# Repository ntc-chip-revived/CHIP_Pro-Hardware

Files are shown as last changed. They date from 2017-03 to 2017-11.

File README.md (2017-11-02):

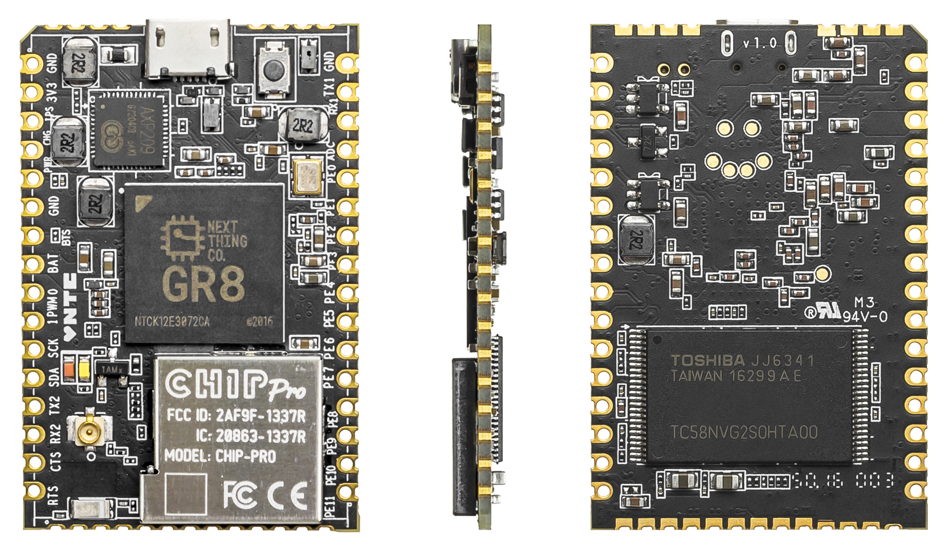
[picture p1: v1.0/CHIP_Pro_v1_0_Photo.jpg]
Image of C.H.I.P. Pro v1.0


# C.H.I.P. Pro Hardware Versions

v1.0 = C.H.I.P. Pro<br>
v0.9 = Early Pre-Cert Developer Kits

# Source Files
C.H.I.P. Pro is designed using OrCAD! 
<br>A free "lite" viewer is available at www.orcad.com

# Documentation
#### C.H.I.P. Pro Datasheet:
https://github.com/NextThingCo/CHIP_Pro-Hardware/blob/master/Datasheets/CHIP_PRO_Datasheet_v1.0.pdf

#### C.H.I.P. Pro Docs:
https://docs.getchip.com/chip_pro.html

#### C.H.I.P. Pro Dev Kit Docs:
https://docs.getchip.com/chip_pro_devkit.html

# Compliance
C.H.I.P. Pro is tested for compliance with, and registered as indicated below with the following regulatory bodies:
REACH,
ROHS,
CE,
FCC (ID: 2AF9F-1337R, 47 CFR 15 Modular Transmitter when used with pre-certified antennas as listed in Datasheet),
IC (ID: 20863-1337R, HVIN CHIP-PRO)

# License
<br />This work is licensed under a <a rel="license" href="http://creativecommons.org/licenses/by/4.0/">Creative Commons Attribution 4.0 International License</a>.

# Contact NTC
**Purchasing:** sales@nextthing.co 
**Technical:** pro@nextthing.co <br>
Join the conversation at https://bbs.nextthing.co/c/CHIP-Pro

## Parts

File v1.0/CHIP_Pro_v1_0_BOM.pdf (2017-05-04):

*********************************************************************************************************************************************

# Next Thing Co. Creative Commons: CC-BY-SA

## docs.nextthing.co

*********************************************************************************************************************************************

### PCBA BOM

Model | C.H.I.P. Pro
Version | v1.0
Item Number | 100456
Date | 5/4/17
Document Revision | v1.01
NAME | CATEGORY | QTY | REF DES | MFG P/N | MANUFACTURER
IC CPU GR8 BGA252 | IC | 1 | U1 | | Next Thing Co.
AXP209 | IC | 1 | U2 | | Allwinner
IC DC-DC LP3220SAB5F SOT23-5 | IC | 2 | U3, U4 | MT3410LA | Pace Electronics
SMD MODULE WIFI | IC | 1 | U5 | 8723DS | FN-link
SMD INDUCTOR 2.2uH DCR<0.1R-1.7A 3518 | Inductor | 5 | L1,L2,L3,L4,L5 | MPA3015S2R2M | Mottotech
SMD LED 0603 white color (e.g. Everlight QTLP603CIWTR or similar) | LED | 1 | D1 | HQ19-2101UWC | HQG
SMD LED EC01-0603QRC-E-Ag pink color (e.g. lowcost versions of Panasonic LNJP12X8ARA or similar) | LED | 1 | D2 | HQ19-2132UFD | HQG
WiFi/Bluetooth Antenna | Antenna | 1 | ANT2 | AA055 | Unictron
SMD TRANSISTOR MMBT3904 NPN SOT-23 | Transistor | 1 | Q2 | MMBT3904 | Pace Electronics
SMD C-MOS N-channel BSN20 SOT-23 | Transistor | 1 | Q1 | 2N7002K | Pace Electronics
SMD JACK MICRO USB A01SB141BH2_4A | Jack | 1 | J4 | U-F-M5DW-Y | Han Rong Parts Co.
SMD KEY SW_4P_TC3061B/IT-1100AE | Switch | 1 | SW2 | K2-1807SA | Han Rong Parts Co.
CHIP CAP 0201 47P 16V NPO | Capacitor | 2 | C16,C31 | CC0201JRNPO8BN470 | YAGEO
CHIP CAP 0201 102 16V +/-20% | Capacitor | 3 | C11,C15,C84 | CC0201KRX7R8BB102 | YAGEO
CHIP CAP 0201 104 10V +/-20% | Capacitor | 1 | C54 | CC0201KRX5R6BB104 | YAGEO
CHIP CAP 0402 105 10V +/-20% | Capacitor | 26 | C4,C18,C19,C23,C34, C52,C57,C58,C60,C61, C62,C63,C65,C69,C70, C71,C72,C74,C77,C78, C79,C80,C81,C82,C83, C85 | CC0402KRX5R6BB105 | YAGEO
CHIP CAP 0603 4.7uF 10V +/-20% | Capacitor | 8 | C5, C6,C7,C21,C26,C27,C 33,C55 | CC0603KRX5R6BB475 | YAGEO
CHIP CAP 0603 10uF 10V +/-20% | Capacitor | 7 | C8,C9,C12,C13,C17,C 28,C48 | CC0603MRX5R6BB106 | YAGEO
CHIP CAP 0805 22uF 10V +/-20% | Capacitor | 2 | C44,C45 | CC0805MKX5R5BB226 | YAGEO
CHIP RESISTOR 0201 24Ohm 1/20W +/-5% | Resistor | 2 | R100,R101 | RC0201JR-0724RL | YAGEO
CHIP RESISTOR 0201 240Ohm 1/16W +/-1% | Resistor | 2 | R2,R3 | RC0201FR-07240RL | YAGEO
CHIP RESISTOR 0201 1KOhm 1/20W +/-5% | Resistor | 3 | R15,R20,R21 | RC0201JR-071KL | YAGEO
CHIP RESISTOR 0201 2KOhm 1/16W +/-1% | Resistor | 2 | R1,R4 | RC0201FR-072KL | YAGEO
CHIP RESISTOR 0201 2.2KOhm 1/20W +/-5% | Resistor | 5 | R22,R59,R60,R61,R62 | RC0201JR-072K2L | YAGEO
CHIP RESISTOR 0201 10KOhm 1/20W +/-5% | Resistor | 8 | NSR1,R5,R9,R10,R46, R47,R51,R64 | RC0201JR-0710KL | YAGEO
CHIP RESISTOR 0201 33KOhm 1/20W +/-5% | Resistor | 5 | R38,R39,R41,R42,R43 | RC0201JR-0733KL | YAGEO
CHIP RESISTOR 0201 47KOhm 1/20W +/-5% | Resistor | 2 | R14,R18 | RC0201JR-0747KL | YAGEO
CHIP RESISTOR 0201 100KOhm 1/20W +/-5% | Resistor | 2 | R48,R49 | RC0201JR-07100KL | YAGEO
CHIP RESISTOR 0201 0Ohm 1/20W +/-5% | Resistor | 2 | R36,R58 | RC0201JR-070RL | YAGEO
CHIP RESISTOR 0402 1Ohm 1/16W +/-5% | Resistor | 2 | R8,R53 | RC0402JR-071RL | YAGEO
CHIP RESISTOR 0201 100KOhm 1/20W +/-1% | Resistor | 2 | R11,R16 | RC0201FR-07100KL | YAGEO
CHIP RESISTOR 0201 150KOhm 1/20W +/-1% | Resistor | 1 | R17 | RC0201FR-07150KL | YAGEO
CHIP RESISTOR 0201 200KOhm 1/20W +/-1% | Resistor | 2 | R13,R57 | RC0201FR-07200KL | YAGEO
CHIP RESISTOR 0603 0.03Ohm 1/8W +/-1% | Resistor | 1 | R7 | RL0603FR-070R03L | YAGEO
CHIP CAP 0201 8p 16V NPO | Capacitor | 1 | C49 | 1.0pF C0201 | YAGEO
CHIP RESISTOR 0201 2KΩ 1/16W ±5% | Resistor | 1 | R19 | RC0201JR-072KL | YAGEO
SLC NAND TC58NVG2S0HTA00 | Memory | 1 | U7 | TC58NVG2S0HTA00 | Toshiba
CHIP CAP 0201 104 6.3V +/-20% | Capacitor | 23 | C1,C2,C3,C22,C32,C3 5,C37,C64,C66,C75,C8 6,C88,C90,C91,C93,C9 4,C95,C96,C97,C98,C1 48,C151,C153 | CC0201KRX5R5BB104 | YAGEO
CHIP RESISTOR 0201 442KΩ 1/16W ±1% | Resistor | 1 | R12 | RC0201FR-07442KL | YAGEO
WiFi Module RF Shield | Sheet metal | 1 | | n/a | Custom
RDASW282/XMSS1R6G0PA-001 | Switch | 1 | U8 | RDASW282 | Arrow China
CHIP RESISTOR 0402 0Ω 1/8W | Resistor | 1 | R32 | RC0402JR-070RL | YAGEO
CHIP CAP 0603 4.7uF 6.3V +/-20% | Capacitor | 9 | C20,C24,C25,C29,C30, C36,C53,C56,C89 | CC0603KRX5R5BB475 | YAGEO
CHIP CAP 0603 10uF 6.3V +/-20% | Capacitor | 7 | C10,C14,C59,C68,C76, C87,C92 | CC0603MRX5R5BB106 | YAGEO
CHIP CAP 0201 20P 16V NPO | Capacitor | 2 | C67, C73 | CC0201JRNPO8BN200 | YAGEO
SMD CRYSTAL 24MHz ±10ppm 20pF | Crystal | 1 | X1 | 7U024000W120 | SJK Crystal Tech
I-PEX Connector | Connector | 1 | ANT1 | C-7.005A0 | HuaChuangxiang
0402 ESD Diode SE10F10B5.0MA | Diode | 5 | ESD1, ESD2, ESD5, ESD3, ESD4 | SE10F10B5.0MA | 芯晶图
SDCW2012-2-900TF | Inductor | 2 | L9,L10 | SDCW2012-2-900TF | Sunlord
| Capacitor | 1 | R33 | 1.2pF C0201 | YAGEO
PCB + PCBA | | 1 | PCB Material + PCBA

1

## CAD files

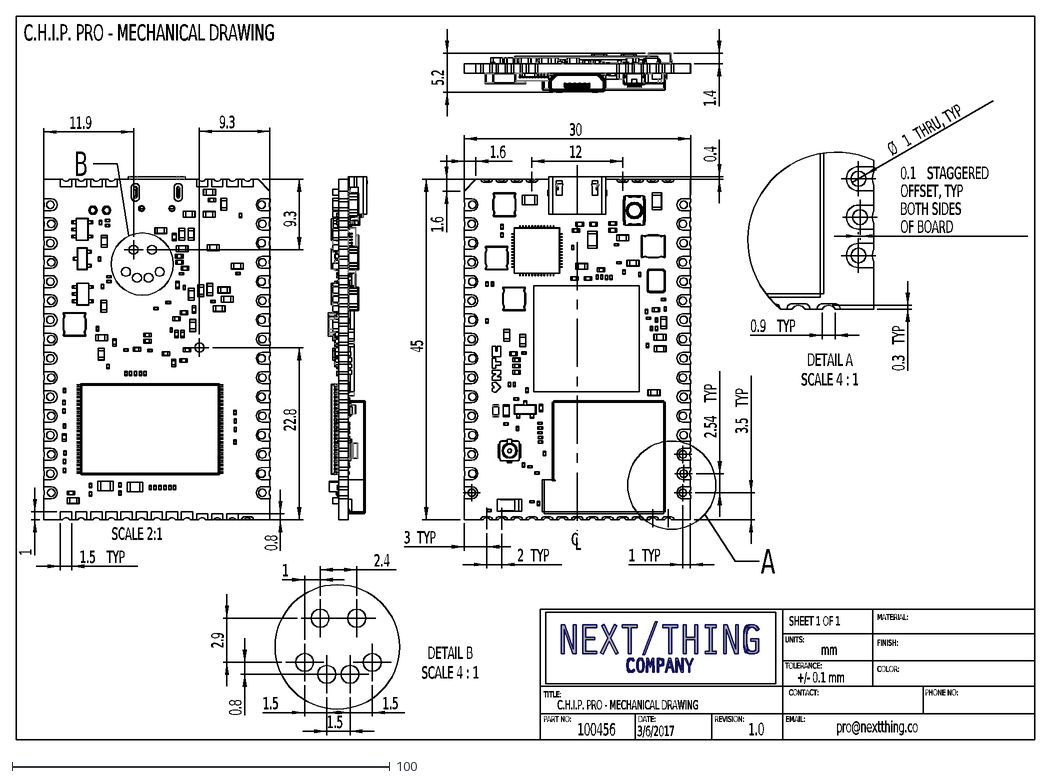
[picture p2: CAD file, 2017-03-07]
Mechanical_Documents/NTC-100456_C.H.I.P._Pro_Mechanical_Drawing_v1.0_2017-03-06.DXF
C.H.I.P. PRO - MECHANICAL DRAWING
1.0
+/- 0.1 mm
FINISH:
COLOR:
REVISION:
UNITS:
TITLE:
mm
pro@nextthing.co
EMAIL:
CONTACT:
SHEET 1 OF 1
DATE:
PHONE NO:
MATERIAL:
3/6/2017
PART NO:
TOLERANCE:
100456
45
30
0.4
1.6
12
2.54
TYP
3.5
1
3
2
C
L
A
1.4
5.2
11.9
9.3
22.8
0.8
1.5
SCALE 2:1
B
0.3
0.1
STAGGERED
OFFSET, TYP
BOTH SIDES
OF BOARD
0.9
Ø
THRU, TYP
DETAIL A
SCALE 4 : 1
2.9
2.4
DETAIL B

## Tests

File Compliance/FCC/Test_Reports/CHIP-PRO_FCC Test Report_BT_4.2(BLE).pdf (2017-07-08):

Report No.: AGC06426160901FE08 Page 1 of 26

# FCC Test Report

## Report No.: AGC08116161202FE08

FCC ID | : 2AF9F-1337R
APPLICATION PURPOSE | : Original Equipment

### PRODUCT DESIGNATION : CHIP Pro

BRAND NAME | : CHIP Pro
MODEL NAME | : CHIP-PRO
CLIENT | : Next Thing Co
DATE OF ISSUE | : Mar. 22, 2017
STANDARD(S) TEST PROCEDURE(S) | : FCC Part 15.247 KDB 558074 v03r05
REPORT VERSION | : V1.0

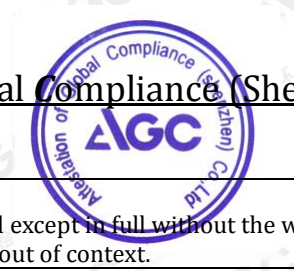
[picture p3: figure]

# Attestation of Global Compliance (Shenzhen) Co., Ltd

### CAUTION:

This report shall not be reproduced except in full without the written permission of the test laboratory and shall not be quoted out of context.

Report No.: AGC08116161202FE08 Page 2 of 26

Report Revise Record

Report Version | Revise Time | Issued Date | Valid Version | Notes
V1.0 | / | Mar. 22, 2017 | Valid | Original Report

Page 3 of 26

TABLE OF CONTENTS

Page 4 of 26

Page 5 of 26

### 1. VERIFICATION OF COMPLIANCE

Applicant | Next Thing Co
Address | 1940 Union St#32, Oakland CA
Manufacturer | Next Thing Co
Address | 1940 Union St#32, Oakland CA
Product Designation | CHIP Pro
Brand Name | CHIP Pro
Test Model | CHIP-PRO
Date of test | Feb. 20, 2017~Mar. 16, 2017
Deviation | None
Condition of Test Sample | Normal
Report Template | AGCRT-US-BLE/RF

WE HEREBY CERTIFY THAT:

The above equipment was tested by Dongguan Precise Testing Service Co., Ltd. The test data, data evaluation, test procedures, and equipment configurations shown in this report were made in accordance with the procedures given in ANSI C63.10 (2013) and the energy emitted by the sample EUT tested as described in this report is in compliance with requirement of FCC Part 15 Rules requirement.

Tested By

Donjon Huang(Huang
Dongyang)

Mar. 16, 2017

Reviewed By

Bart Xie(Xie Xiaobin) | Mar. 22, 2017

Approved By

Solger Zhang(Zhang Hongyi)
Authorized Officer | Mar. 22, 2017

Page 6 of 26

2.GENERAL INFORMATION
2.1PRODUCT DESCRIPTION
The EUT is designed as “CHIP Pro ”. It is designed by way of utilizing the FHSS technology to achieve the system operation.

A major technical description of EUT is described as following

### 2.2 RELATED SUBMITTAL(S)/GRANT(S)

This submittal(s) (test report) is intended for FCC ID: 2AF9F-1337R filing to comply with Section 15.247of the FCC Part 15, Subpart C Rules.

2.3TEST METHODOLOGY
All measurements contained in this report were conducted with KDB 558074 D01 DTS Meas Guidance v03r05, American National Standard for Methods of Measurement of Radio-Noise Emissions from Low-Voltage Electrical and Electronic Equipment in the range of 9 kHz to 40 GHz.
The equipment under test (EUT) was configured to measure its highest possible emission level. The test modes were adapted accordingly in reference to the Operating Instructions. The EUT was tested in all three orthogonal planes and the worse case was showed.

### 2.4 TEST FACILITY

### 2.5 SPECIAL ACCESSORIES

Refer to section 2.2.

Operation Frequency | 2.402 GHz to 2.480GHz
Bluetooth Version | V4.2
Modulation | GFSK
Number of channels | 40 Channel(37 Hopping Channel,3 advertising Channel)
Antenna Designation | AA107:PCB Antenna HCX-P321:PCB Antenna FXP73: PCB Antenna AA055: Ceramic Antenna
Antenna Gain | AA107:3.3dBi; HCX-P321:2dBi; FXP73:2.5dBi; AA055:2.5dBi
Hardware Version | V1.0
Software Version | Fcc-20170109-b6281346
Power Supply | DC5V by PC
Site | Dongguan Precise Testing Service Co., Ltd.
Location | Building D,Baoding Technology Park,Guangming Road2,Dongcheng District, Dongguan, Guangdong, China,
FCC Registration No. | 371540
Description | The test site is constructed and calibrated to meet the FCC requirements in documents ANSI C63.10:2013.

Page 7 of 26

### 2.6 EQUIPMENT MODIFICATIONS

Not available for this EUT intended for grant.

### 3. SYSTEM TEST CONFIGURATION

### 3.1 CONFIGURATION OF TESTED SYSTEM

Configuration:

USB Cable

### 3.2 EQUIPMENT USED IN TESTED SYSTEM

Item | Equipment | Model No. | ID or Specification | Note
1 | CHIP Pro | CHIP-PRO | 2AF9F-1337R | EUT
2 | Lenovo | B460 | WB03928113 | PC
3 | USB Cable | N/A | N/A | Accessory

ALL TEST EQUIPMENT LIST
FOR RADIATED EMISSION TEST (BELOW 1GHZ)
Radiated Emission Test Site
Name of Equipment | Manufacturer | Model Number | Serial
| | | Number | Last Calibration | Due Calibration
EMI Test Receiver | Rohde & Schwarz | ESCI | 101417 | July 3, 2016 | July 2, 2017
Trilog Broadband Antenna (25M-1GHz) | SCHWARZBECK | VULB9160 | 9160-3355 | July 3, 2016 | July 2, 2017
Signal Amplifier | SCHWARZBECK | BBV 9475 | 9745-0013 | July 3, 2016 | July 2, 2017
RF Cable | SCHWARZBECK | AK9515E | 96221 | July 3, 2016 | July 2, 2017
3m Anechoic Chamber | CHENGYU | 966 | PTS-001 | June 5, 2016 | June 4, 2017
MULTI-DEVICE Positioning Controller | Max-Full | MF-7802 | MF780208339 | N/A | N/A
Active loop antenna (9K-30MHz) | Schwarzbeck | FMZB1519 | 1519-038 | June 5, 2016 | June 4, 2017
Spectrum analyzer | Agilent | E4407B | MY46185649 | June 5, 2016 | June 4, 2017
Power Probe | R&S | NRP-Z23 | 100323 | July 24,2016 | July 23,2017
RF attenuator | N/A | RFA20db | 68 | N/A | N/A
EUT | PC

Page 8 of 26

FOR RADIATED EMISSION TEST (1GHZ ABOVE)
Radiated Emission Test Site
Name of Equipment | Manufacturer | Model Number | Serial
| | | Number | Last Calibration | Due Calibration
EMI Test Receiver | Rohde & Schwarz | ESCI | 101417 | July 3, 2016 | July 2, 2017
Horn Antenna (1G-18GHz) | SCHWARZBECK | BBHA9120D | 9120D-1246 | July 10, 2016 | July 9, 2017
Spectrum Analyzer | Agilent | E4411B | MY4511453 | July 3, 2016 | July 2, 2017
Signal Amplifier | SCHWARZBECK | BBV 9718 | 9718-269 | July 6, 2016 | July 5, 2017
RF Cable | SCHWARZBECK | AK9515H | 96220 | July 7, 2016 | July 6, 2017
3m Anechoic Chamber | CHENGYU | 966 | PTS-001 | June 5, 2016 | June 4, 2017
MULTI-DEVICE Positioning Controller | Max-Full | MF-7802 | MF780208339 | N/A | N/A
Horn Ant (18G-40GHz) | Schwarzbeck | BBHA 9170 | 9170-181 | June 5, 2016 | June 4, 2017
Power Probe | R&S | NRP-Z23 | 100323 | July 24,2016 | July 23,2017
RF attenuator | N/A | RFA20db | 68 | N/A | N/A
Conducted Emission Test Site Name of
EMI Test Receiver | Rohde & Schwarz | ESCI | 101417 | July 3, 2016 | July 2, 2017
Artificial Mains Network | Narda | L2-16B | 000WX31025 | July 7, 2016 | July 6, 2017
Artificial Mains Network (AUX) | Narda | L2-16B | 000WX31026 | July 7, 2016 | July 6, 2017
RF Cable | SCHWARZBECK | AK9515E | 96222 | July 3, 2016 | July 2, 2017
Shielded Room | CHENGYU | 843 | PTS-002 | June 5,2016 | June 4,2017
Equipment | Manufacturer | Model Number | Serial Number | Last
Calibration | Due Calibration

Conducted Emission Test Site Name of

EMI Test Receiver | Rohde & Schwarz | ESCI | 101417 | July 3, 2016 | July 2, 2017
Artificial Mains Network | Narda | L2-16B | 000WX31025 | July 7, 2016 | July 6, 2017
Artificial Mains Network (AUX) | Narda | L2-16B | 000WX31026 | July 7, 2016 | July 6, 2017
RF Cable | SCHWARZBECK | AK9515E | 96222 | July 3, 2016 | July 2, 2017
Shielded Room | CHENGYU | 843 | PTS-002 | June 5,2016 | June 4,2017
Equipment | Manufacturer | Model Number | Serial Number | Last
Calibration | Due Calibration

Page 9 of 26

### 4. SUMMARY OF TEST RESULTS

### 5. DESCRIPTION OF TEST MODES

The EUT has been operated in three modulations: GFSK independently.
NO. | TEST MODE DESCRIPTION
1 | Low channel TX
2 | Middle channel TX
3 | High channel TX
4 | Normal Operating (BT)
Note:
1. All the test modes can be supply by PC, only the result of the worst case was recorded in the report if no any records.
2. For Radiated Emission, 3axis were chosen for testing for each applicable mode.
3. Eut is operating at its maximum duty cycle>or equal 98%
FCC RULES | DESCRIPTION OF TEST | RESULT
§15.203 | Antenna Requirement | Compliant
§15.209 §15.247(d) | Radiated Emission | Compliant
§15.247(d) | Band Edges | Compliant
§15.247 | 6 dB Bandwidth | Compliant
§15.247(b) | Conducted Power | Compliant
§15.247(e) | Maximum Conducted Output Power SPECTRAL Density | Compliant
§15.207 | Conduction Emission | Compliant

Page 10 of 26

### 6. ANTENNA REQUIREMENT

### 6.1. STANDARD APPLICABLE

According to FCC 15.203, An intentional radiator shall be designed to ensure that no antenna other than that furnished by the responsible party shall be used with the device. The use of a permanently attached antenna or of an antenna that uses a unique coupling to the intentional radiator shall be considered sufficient to comply with the provisions of this Section. The manufacturer may design the unit so that a broken antenna can be replaced by the user, but the use of a standard antenna jack or electrical connector is prohibited. This requirement does not apply to carrier current devices or to devices operated under the provisions of Sections 15.211, 15.213, 15.217, 15.219, or 15.221. Further, this requirement does not apply to intentional radiators that must be professionally installed, such as perimeter protection systems and some field disturbance sensors, or to other intentional radiators which, in accordance with Section 15.31(d), must be measured at the installation site. However, the installer shall be responsible for ensuring that the proper antenna is employed so that the limits in this Part are not exceeded.

### 6.2. TEST RESULT

In addition to permanent antenna, the product could be connected with some detachable antennas.
Note: The U.FL / IPEX antenna connector is not considered as a type of unique antenna coupling. However, as the installation of this module would be done by OEM integrator, it could be considered as a professional installation.

Page 11 of 26

### 7. RADIATED EMISSION

### 7.1 MEASUREMENT PROCEDURE

1. Configure the EUT according to ANSI C63.10. The EUT was placed on the top of the turntable 0.8 meter above ground. The phase center of the receiving antenna mounted on the top of a height-variable antenna tower was placed 3 meters far away from the turntable.
2. Power on the EUT and all the supporting units. The turntable was rotated by 360 degrees to determine the position of the highest radiation.
3. The height of the broadband receiving antenna was varied between one meter and four meters above ground to find the maximum emissions field strength of both horizontal and vertical polarization.
4. For each suspected emissions, the antenna tower was scan (from 1 M to 4 M) and then the turntable was rotated (from 0 degree to 360 degrees) to find the maximum reading.
5. Set the test-receiver system to Peak or CISPR quasi-peak Detect Function with specified bandwidth under Maximum Hold Mode.
6. For emissions above 1GHz, use 1MHz VBW and RBW for peak reading. Then 1MHz RBW and 10Hz VBW for average reading in spectrum analyzer. The EUT was placed on the top of the turntable 1.5 meter above ground. The phase center of the receiving antenna mounted on the top of a height-variable antenna tower was placed 3 meters far away from the turntable.
7. When the radiated emissions limits are expressed in terms of the average value of the emissions, and pulsed operation is employed, the measurement field strength shall be determined by averaging over one complete pulse train, including blanking intervals, as long as the pulse train does not exceed 0.1 seconds. As an alternative (provided the transmitter operates for longer than 0.1 seconds) or in cases where the pulse train exceeds 0.1 seconds, the measured field strength shall be determined from the average absolute voltage during a 0.1 second interval during which the field strength is at its maximum values. 8.If the emissions level of the EUT in peak mode was 3 dB lower than the average limit specified, then testing will be stopped and peak values of EUT will be reported, otherwise, the emissions which do not have 3 dB margin will be repeated one by one using the quasi-peak method for below 1GHz.
9. For testing above 1GHz, the emissions level of the EUT in peak mode was lower than average limit (that means the emissions level in peak mode also complies with the limit in average mode), then testing will be stopped and peak values of EUT will be reported, otherwise, the emissions will be measured in average mode again and reported.
10. In case the emission is lower than 30MHz, loop antenna has to be used for measurement and the recorded data should be QP measured by receiver. High - Low scan is not required in this case.

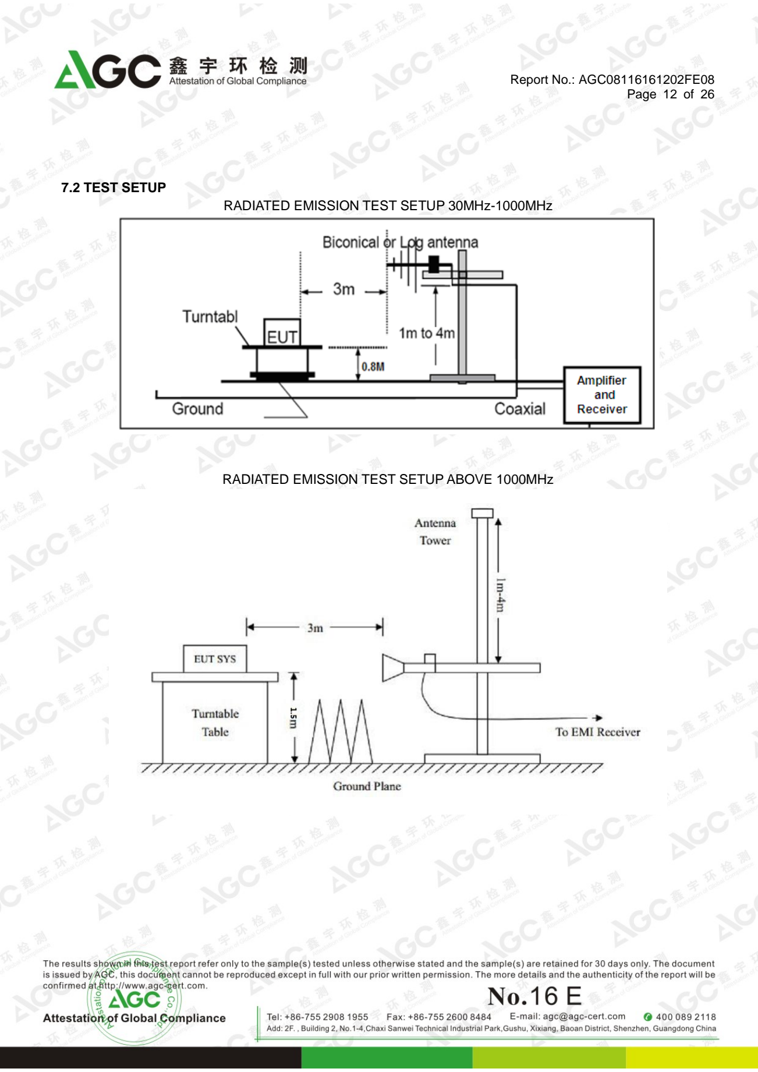
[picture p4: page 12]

Page 12 of 26

### 7.2 TEST SETUP

RADIATED EMISSION TEST SETUP 30MHz-1000MHz

RADIATED EMISSION TEST SETUP ABOVE 1000MHz

Page 13 of 26

### 7.3 LIMITS AND MEASUREMENT RESULT

15.209 Limit in the below table has to be followed
Frequencies (MHz) | Field Strength (micorvolts/meter) | Measurement Distance (meters)
0.009~0.490 | 2400/F(KHz) | 300
0.490~1.705 | 24000/F(KHz) | 30
1.705~30.0 | 30 | 30
30~88 | 100 | 3
88~216 | 150 | 3
216~960 | 200 | 3
Above 960 | 500 | 3

Note: All modes were tested For restricted band radiated emission,
the test records reported below are the worst result compared to other modes.

### 7.4 TEST RESULT

RADIATED EMISSION BELOW 30MHZ No emission found between lowest internal used/generated frequencies to 30MHz.

Page 14 of 26

RADIATED EMISSION BELOW 1GHZ RADIATED EMISSION TEST- (30MHZ-1GHZ) -HORIZONTAL

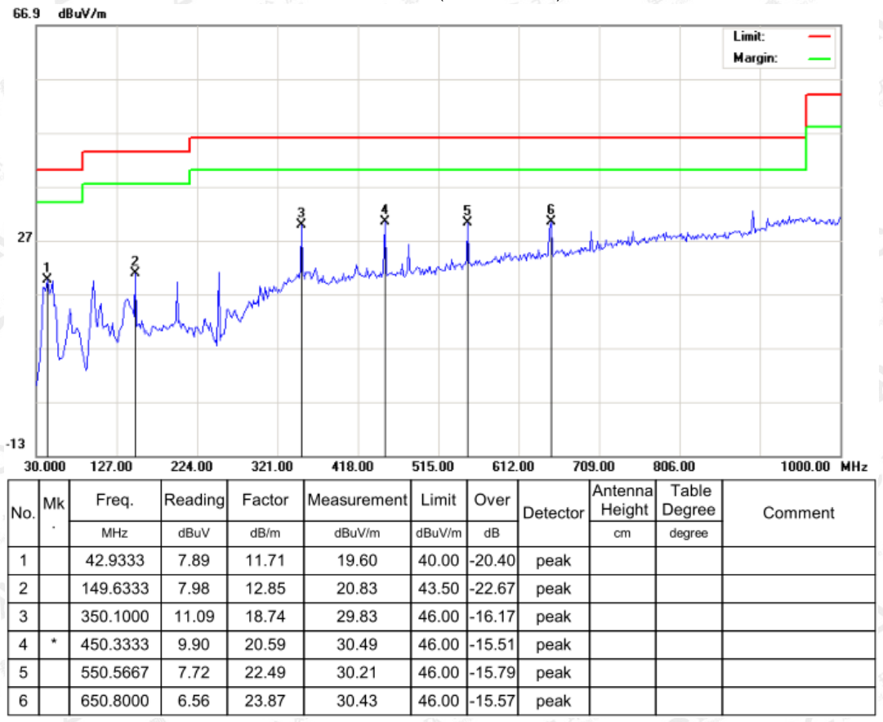
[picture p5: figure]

RESULT: PASS

Page 15 of 26

RADIATED EMISSION TEST- (30MHZ-1GHZ) -VERTICAL

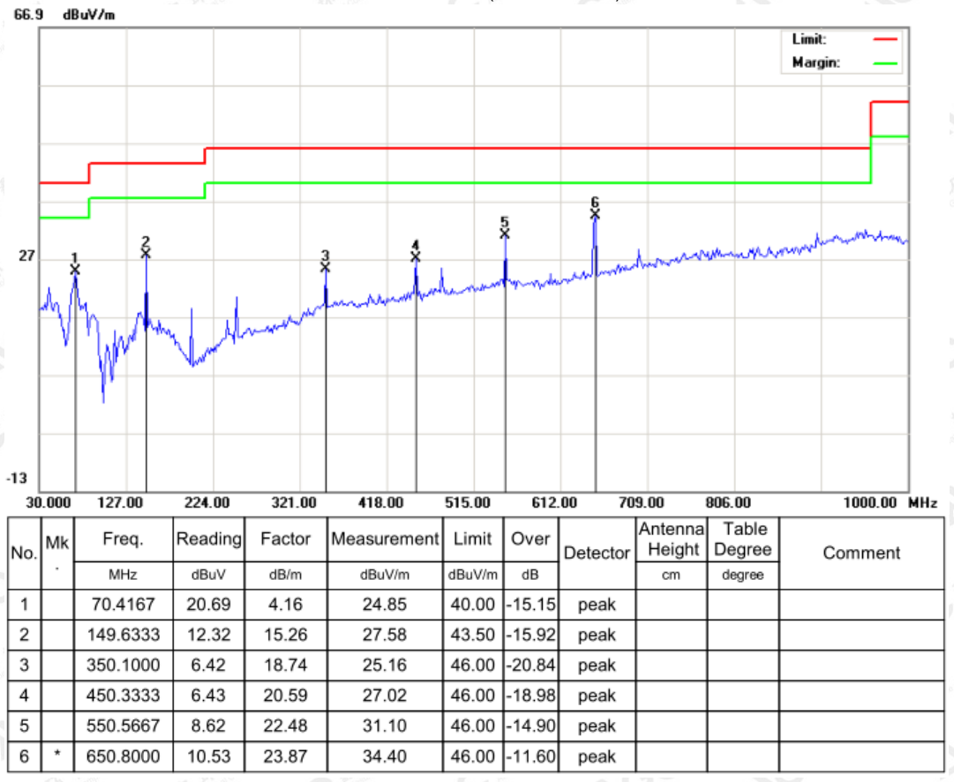
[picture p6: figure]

RESULT: PASS

Note: 1. Factor=Antenna Factor + Cable loss, Margin=Measurement-Limit.
2. The “Factor” value can be calculated automatically by software of measurement system.
3. All modes were tested (matched worst case antenna), only the worst case record in the report

Page 16 of 26

RADIATED EMISSION ABOVE 1GHZ

Frequency | Meter Reading | Factor | Emission Level | Limits | Margin | Detector | Comment
(MHz) | (dBμV) | (dB) | (dBμV/m) | (dBμV/m) | (dB) | Type
Low Channel (2402 MHz)
4804 | 40.22 | 10.44 | 50.66 | 74 | -23.34 | Pk | Horizontal
4804 | 29.17 | 10.44 | 39.61 | 54 | -14.39 | AV | Horizontal
7206 | 42.06 | 12.39 | 54.45 | 74 | -19.55 | pk | Horizontal
7206 | 29.08 | 12.39 | 41.47 | 54 | -12.53 | AV | Horizontal
4804 | 43.10 | 10.4 | 53.50 | 74 | -20.50 | Pk | Vertical
4804 | 28.54 | 10.4 | 38.94 | 54 | -15.06 | AV | Vertical
7206 | 32.70 | 12.75 | 45.45 | 74 | -28.55 | Pk | Vertical
7206 | 27.95 | 12.75 | 40.70 | 54 | -13.30 | AV | Vertical
Mid Channel (2440 MHz)
4880 | 38.59 | 10.4 | 48.99 | 74 | -25.01 | Pk | Horizontal
4880 | 29.75 | 10.4 | 40.15 | 54 | -13.85 | AV | Horizontal
7320 | 40.26 | 12.75 | 53.01 | 74 | -20.99 | Pk | Horizontal
7320 | 30.80 | 12.75 | 43.55 | 54 | -10.45 | AV | Horizontal
4880 | 43.31 | 10.39 | 53.70 | 74 | -20.30 | Pk | Vertical
4880 | 27.98 | 10.44 | 38.42 | 54 | -15.58 | AV | Vertical
7320 | 39.87 | 12.68 | 52.55 | 74 | -21.45 | Pk | Vertical
7320 | 30.90 | 12.68 | 43.58 | 54 | -10.42 | AV | Vertical
High Channel (2480 MHz)
4960 | 43.23 | 10.39 | 53.62 | 74 | -20.38 | pk | Horizontal
4960 | 26.04 | 10.39 | 36.43 | 54 | -17.57 | AV | Horizontal
7440 | 39.36 | 12.68 | 52.04 | 74 | -21.96 | pk | Horizontal
7440 | 30.71 | 12.68 | 43.39 | 54 | -10.61 | AV | Horizontal
4960 | 37.05 | 10.39 | 47.44 | 74 | -26.56 | pk | Vertical
4960 | 27.13 | 10.39 | 37.52 | 54 | -16.48 | AV | Vertical
7440 | 39.85 | 12.68 | 52.53 | 74 | -21.47 | pk | Vertical
7440 | 30.97 | 12.68 | 43.65 | 54 | -10.35 | AV | Vertical

RESULT: PASS

Note: 1~25GHz scan with GFSK. No recording in the test report at least have 20dB margin. Factor = Antenna Factor + Cable Loss – Pre-amplifier.
Emission Level = Meter Reading + Factor
Margin = Emission - Leve Limit
All modes were tested(matched worst case antenna), only the worst case record in the report

Page 17 of 26

### 8. BAND EDGE EMISSION

### 8.1. MEASUREMENT PROCEDURE

1)Radiated restricted band edge measurements
The radiated restricted band edge measurements are measured with an EMI test receiver connected to the receive antenna while the EUT is transmitting
2)Conducted Emissions at the bang edge
a)The transmitter output was connected to the spectrum analyzer
b)Set RBW=100kHz,VBW=300kHz
c)Suitable frequency span including 100kHz bandwidth from band edge

### 8.2. TEST SET-UP

Radiated same as 6.2

Conducted set up

cable

EUT | Spectrum analyzer

Page 18 of 26

### 8.3. Radiated Test Result

Frequency | Reading Meter | Factor | Emission Level | Limits | Margin | Detector | Comment
(MHz) | (dBμV) | (dB) | (dBμV/m) | (dBμV/m) | (dB) | Type
Low Channel (2402 MHz)
2399.9 | 69.44 | -13 | 56.44 | 74 | -17.56 | peak | Horizontal
2399.9 | 55.13 | -13 | 42.13 | 54 | -11.87 | AVG | Horizontal
2400 | 65.17 | -12.99 | 52.18 | 74 | -21.82 | peak | Horizontal
2400 | 51.62 | -12.99 | 38.63 | 54 | -15.37 | AVG | Horizontal
2399.9 | 64.24 | -12.97 | 51.27 | 74 | -22.73 | peak | Vertical
2399.9 | 52.13 | -12.97 | 39.16 | 54 | -14.84 | AVG | Vertical
2400 | 66.18 | -12.94 | 53.24 | 74 | -20.76 | peak | Vertical
2400 | 54.18 | -12.94 | 41.24 | 54 | -12.76 | AVG | Vertical
High Channel (2480 MHz)
2483.5 | 68.40 | -12.78 | 55.62 | 74 | -18.38 | peak | Horizontal
2483.5 | 56.92 | -12.78 | 44.14 | 54 | -9.86 | AVG | Horizontal
2483.6 | 67.31 | -12.77 | 54.54 | 74 | -19.46 | peak | Horizontal
2483.6 | 54.25 | -12.77 | 41.48 | 54 | -12.52 | AVG | Horizontal
2483.5 | 70.36 | -12.76 | 57.60 | 74 | -16.40 | peak | Vertical
2483.5 | 53.45 | -12.76 | 40.69 | 54 | -13.31 | AVG | Vertical
2483.6 | 65.98 | -12.72 | 53.26 | 74 | -20.74 | peak | Vertical
2483.6 | 53.43 | -12.72 | 40.71 | 54 | -13.29 | AVG | Vertical

RESULT: PASS
Note: Factor=Antenna Factor + Cable loss - Amplifier gain,
Emission Level = Meter Reading + Factor
Margin= Emission Level -Limit.
The “Factor” value can be calculated automatically by software of measurement system.
All modes were tested (matched worst case antenna), only the worst case record in the report

Page 19 of 26

### 8.4. Conducted Test Result

Test Graph

Graphs

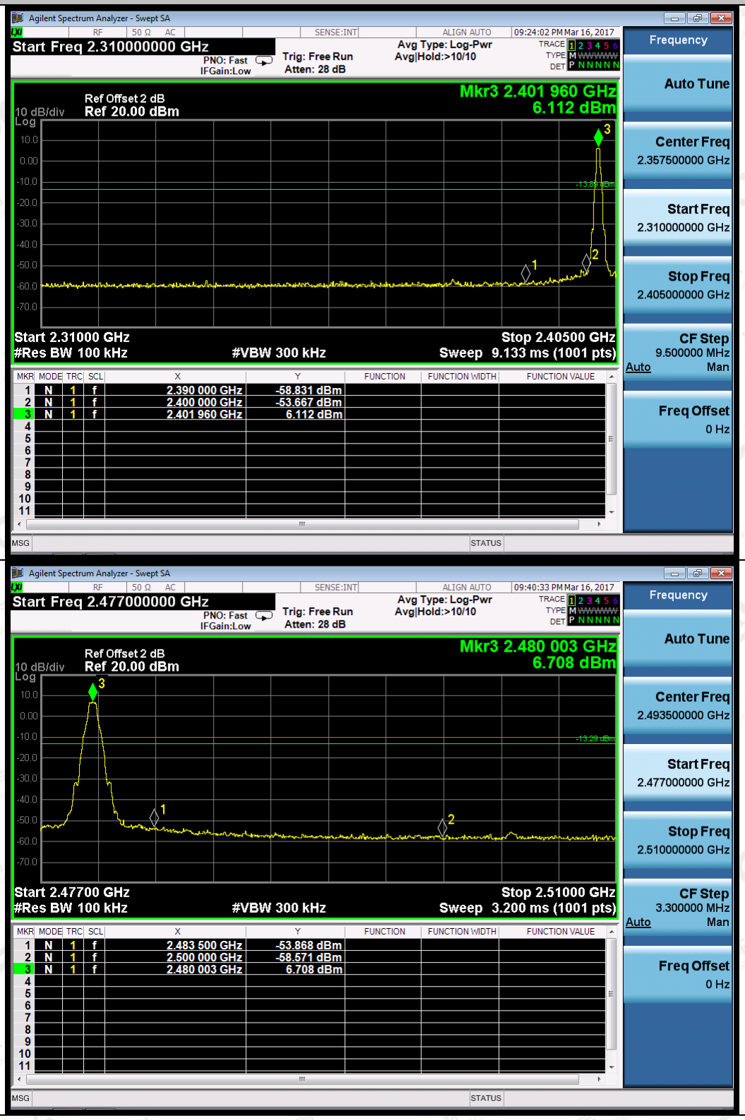
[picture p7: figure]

LCH

HCH

Page 20 of 26

9. 6DB BANDWIDTH

### 9.1. TEST PROCEDURE

1. Connect EUT RF output port to the Spectrum Analyzer through an RF attenuator
2. Set the EUT Work on the top, the middle and the bottom operation frequency individually.
3. Set SPA Centre Frequency = Operation Frequency, RBW= 100 KHz, VBW≥RBW.
4. Set SPA Trace 1 Max hold, then View.

### 9.2. SUMMARY OF TEST RESULTS/PLOTS

Mode | Channel | 6dB Bandwidth [KHz] | Verdict
BLE | LCH | 513.4 | PASS
BLE | MCH | 512.2 | PASS
BLE | HCH | 514.7 | PASS
Note: Two transmit antennas had been tested, the antenna 1 was the worst case and record in the test report.

Test Graph

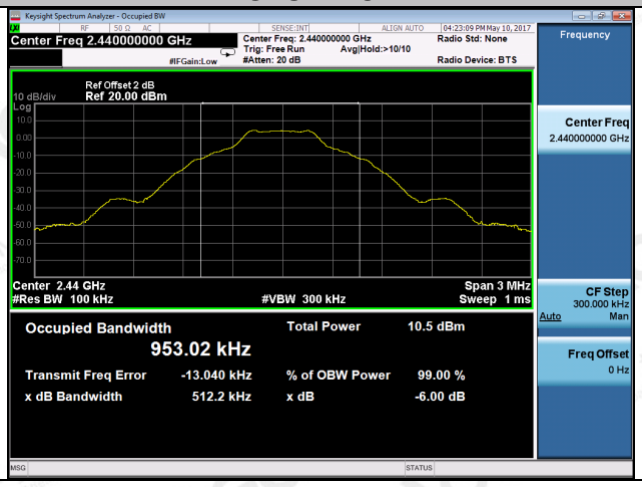
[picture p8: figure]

GFSK-LCH | GFSK-MCH

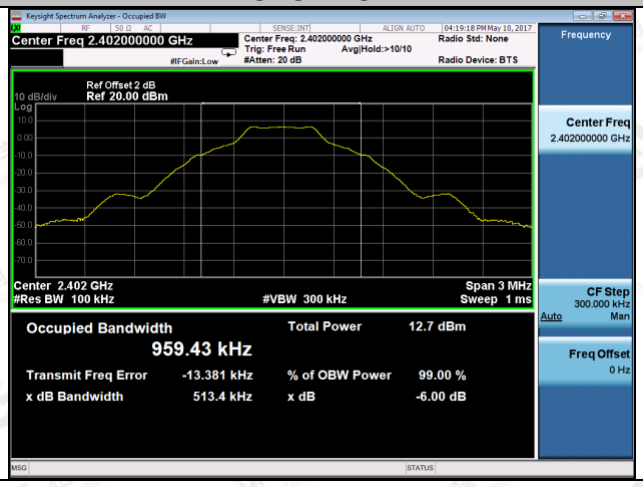
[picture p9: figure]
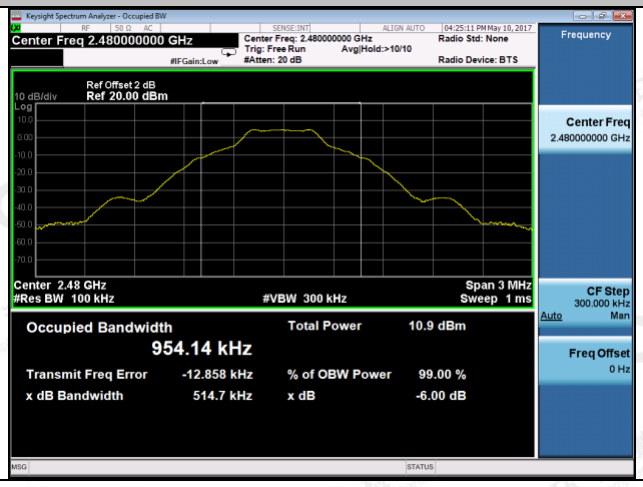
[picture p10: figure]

GFSK-HCH

Page 21 of 26

### 10. CONDUCTED OUTPUT POWER

### 10.1. MEASUREMENT PROCEDURE

1. Connect EUT RF output port to the Spectrum Analyzer through an RF attenuator
2. Set the EUT Work on the top, middle and the bottom operation frequency individually.
3. Use the following spectrum analyzer settings:
Set the RBW ≥ DTS bandwidth
Set the VBW ≥ 3 x RBW
Set the span ≥ 3 x RBW
Detector = peak
Sweep time = auto couple
Trace mode = max hold
4. Allow the trace to stabilize. Use peak marker function to determine the peak amplitude level
5. Record the result form the Spectrum Analyzer.
Note：The EUT was tested according to KDB 558074 for compliance to FCC 47CFR 15.247 requirements.

### 10.2. TEST SET-UP (BLOCK DIAGRAM OF CONFIGURATION)

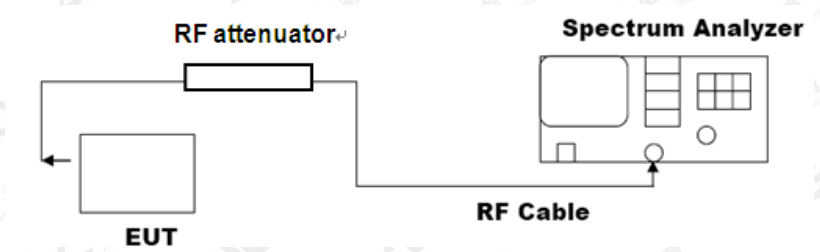
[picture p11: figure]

### 10.3. LIMITS AND MEASUREMENT RESULT

Channel | Peak Power (dBm) | Applicable Limits (dBm) | Pass/Fail
Ant1 | Ant2
Low Channel | 5.175 | -10.670 | 30 | Pass
Middle Channel | 5.252 | -10.666 | 30 | Pass
High Channel | 6.277 | -10.115 | 30 | Pass

Page 22 of 26

### 11. MAXIMUM CONDUCTED OUTPUT POWER SPECTRAL DENSITY

### 11.1 MEASUREMENT PROCEDURE

(1). Connect EUT RF output port to the Spectrum Analyzer through an RF attenuator
(2). Set the EUT Work on the top, the middle and the bottom operation frequency individually.
(3). Set SPA Trace 1 Max hold, then View.
Note: The EUT was tested according to KDB 558074 for compliance to FCC 47CFR 15.247 requirements.

### 11.2 TEST SET-UP (BLOCK DIAGRAM OF CONFIGURATION)

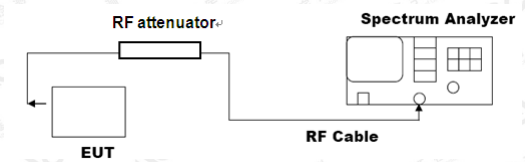
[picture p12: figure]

### 11.3 LIMITS AND MEASUREMENT RESULT

Mode | Channel | PSD [dBm/3kHz] | Limit[dBm/3kHz] | Verdict
Ant1 | Ant2
BLE | LCH | -2.656 | -19.804 | 8 | PASS
BLE | MCH | -2.515 | -19.811 | 8 | PASS
BLE | HCH | -2.984 | -19.554 | 8 | PASS

Page 23 of 26

## 12. CONDUCTED SPURIOUS EMISSION

### 12.1. MEASUREMENT PROCEDURE

1. Connect EUT RF output port to the Spectrum Analyzer through an RF attenuator
2. Set the EUT Work on the top, the Middle and the bottom operation frequency individually.
3. Set the Span = wide enough to capture the peak level of the in-band emission and all spurious emissions from the lowest frequency generated in the EUT up through the 10th harmonic.
RBW = 100 kHz; VBW ≥ RBW; Sweep = auto; Detector function = peak.
4. Set SPA Trace 1 Max hold, then View.
Note: The EUT was tested according to DA000705 for compliance to FCC 47CFR 15.247 requirements. Owing to satisfy the requirements of the number of measurement points, we set the RBW=1MHz, VBW＞RBW, scan up through 10th harmonic, and consider the tested results as the worst case, if the tested results conform to the requirement, we can deem that the real tested results(set the RBW=100KHz, VBW＞RBW) are conform to the requirement.

### 12.2. TEST SET-UP (BLOCK DIAGRAM OF CONFIGURATION)

The same as described in section 8.2

### 12.3. MEASUREMENT EQUIPMENT USED

The same as described in section 6

### 12.4. LIMITS AND MEASUREMENT RESULT

LIMITS AND MEASUREMENT RESULT

Applicable Limits

Measurement Result

Test Data | Criteria
In any 100 KHz Bandwidth Outside the frequency band in which the spread spectrum intentional radiator is operating, the radio frequency power that is produce by the intentional radiator shall be at least 20 dB below that in 100KHz bandwidth within the band that contains the highest level of the desired power. In addition, radiation emissions which fall in the restricted bands, as defined in §15.205(a), must also comply with the radiated emission limits specified in§15.209(a)) | At least -20dBc than the limit Specified on the BOTTOM Channel | PASS
| At least -20dBc than the limit Specified on the TOP Channel | PASS


Page 24 of 26

Test Graph

GFSK-LCH | GFSK-LCH
GFSK-LCH | GFSK-MCH
GFSK-MCH | GFSK-MCH

Page 25 of 26


GFSK-HCH | GFSK-HCH


GFSK-HCH


Note: All modes were tested, only the worst case record in the report.

## APPENDIX A: PHOTOGRAPHS OF TEST SETUP


Page 26 of 26

FCC RADIATED EMISSION TEST SETUP

----END OF REPORT----

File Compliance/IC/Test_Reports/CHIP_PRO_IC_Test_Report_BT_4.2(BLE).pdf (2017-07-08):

Report No.: AGC06426160901CE08 Page 1 of 26

# IC Test Report

## Report No.: AGC08116161202CE08

IC ID | : 20863-1337R
APPLICATION PURPOSE | : Original Equipment

### PRODUCT DESIGNATION : CHIP Pro

BRAND NAME | : CHIP Pro
MODEL NAME | : CHIP-PRO
CLIENT | : Next Thing Co
DATE OF ISSUE | : Mar. 22, 2017
STANDARD(S) TEST PROCEDURE(S) | : RSS-247, ISSUE 1 RSS-Gen, ISSUE 4 ANSI C63.10
REPORT VERSION | : V1.0


# Attestation of Global Compliance (Shenzhen) Co., Ltd

### CAUTION:

This report shall not be reproduced except in full without the written permission of the test laboratory and shall not be quoted out of context.

Report No.: AGC08116161202CE08 Page 2 of 26

Report Revise Record

Report Version | Revise Time | Issued Date | Valid Version | Notes
V1.0 | / | Mar. 22, 2017 | Valid | Original Report

Page 3 of 26

TABLE OF CONTENTS

Page 4 of 26

Page 5 of 26

### 1. VERIFICATION OF COMPLIANCE

Applicant | Next Thing Co
Address | 1940 Union St#32, Oakland CA
Manufacturer | Next Thing Co
Address | 1940 Union St#32, Oakland CA
Product Designation | CHIP Pro
Brand Name | CHIP Pro
Test Model | CHIP-PRO
Date of test | Feb. 20, 2017~Mar. 16, 2017
Deviation | None
Condition of Test Sample | Normal
Report Template | AGCRT-US-BLE/RF

WE HEREBY CERTIFY THAT:

The above equipment was tested by Dongguan Precise Testing Service Co., Ltd. The test data, data evaluation, test procedures, and equipment configurations shown in this report were made in accordance with the procedures given in ANSI C63.10 (2013) and the energy emitted by the sample EUT tested as described in this report is in compliance with requirement of RSS-247 Rules requirement.

Tested By

Donjon Huang(Huang
Dongyang)

Mar. 16, 2017

Reviewed By

Bart Xie(Xie Xiaobin) | Mar. 22, 2017

Approved By

Solger Zhang(Zhang Hongyi)
Authorized Officer | Mar. 22, 2017

Page 6 of 26

2.GENERAL INFORMATION
2.1PRODUCT DESCRIPTION
The EUT is designed as “CHIP Pro”. It is designed by way of utilizing the FHSS technology to achieve the system operation.

A major technical description of EUT is described as following

### 2.2 RELATED SUBMITTAL(S)/GRANT(S)

This submittal(s) (test report) is intended for IC ID: 20863-1337R filing to comply with RSS-247.

2.3TEST METHODOLOGY
All measurements contained in this report were conducted with ANSI C63.10.
The equipment under test (EUT) was configured to measure its highest possible emission level. The test modes were adapted accordingly in reference to the Operating Instructions. The EUT was tested in all three orthogonal planes and the worse case was showed.

### 2.4 TEST FACILITY

### 2.5 SPECIAL ACCESSORIES

Refer to section 2.2.

### 2.6 EQUIPMENT MODIFICATIONS

Not available for this EUT intended for grant.

Operation Frequency | 2.402 GHz to 2.480GHz
Bluetooth Version | V4.2
Modulation | GFSK
Number of channels | 40 Channel(37 Hopping Channel,3 advertising Channel)
Antenna Designation | AA107:PCB Antenna HCX-P321:PCB Antenna FXP73: PCB Antenna AA055: Ceramic Antenna
Antenna Gain | AA107:3.3dBi; HCX-P321:2dBi; FXP73:2.5dBi; AA055:2.5dBi
Hardware Version | V1.0
Software Version | fcc-20170109-b6281346
Power Supply | DC5V by PC
Site | Dongguan Precise Testing Service Co., Ltd.
Location | Building D,Baoding Technology Park,Guangming Road2,Dongcheng District, Dongguan, Guangdong, China,
FCC Registration No. | 371540
Description | The test site is constructed and calibrated to meet the FCC requirements in documents ANSI C63.10:2013.

Page 7 of 26

### 3. SYSTEM TEST CONFIGURATION

### 3.1 CONFIGURATION OF TESTED SYSTEM

Configuration:

USB Cable

### 3.2 EQUIPMENT USED IN TESTED SYSTEM

Item | Equipment | Model No. | ID or Specification | Note
1 | CHIP Pro | CHIP-PRO | 2AF9F-1337R | EUT
2 | Lenovo | B460 | WB03928113 | PC
3 | USB Cable | N/A | N/A | Accessory

ALL TEST EQUIPMENT LIST
FOR RADIATED EMISSION TEST (BELOW 1GHZ)
Radiated Emission Test Site
Name of Equipment | Manufacturer | Model Number | Serial
| | | Number | Last Calibration | Due Calibration
EMI Test Receiver | Rohde & Schwarz | ESCI | 101417 | July 3, 2016 | July 2, 2017
Trilog Broadband Antenna (25M-1GHz) | SCHWARZBECK | VULB9160 | 9160-3355 | July 3, 2016 | July 2, 2017
Signal Amplifier | SCHWARZBECK | BBV 9475 | 9745-0013 | July 3, 2016 | July 2, 2017
RF Cable | SCHWARZBECK | AK9515E | 96221 | July 3, 2016 | July 2, 2017
3m Anechoic Chamber | CHENGYU | 966 | PTS-001 | June 5, 2016 | June 4, 2017
MULTI-DEVICE Positioning Controller | Max-Full | MF-7802 | MF780208339 | N/A | N/A
Active loop antenna (9K-30MHz) | Schwarzbeck | FMZB1519 | 1519-038 | June 5, 2016 | June 4, 2017
Spectrum analyzer | Agilent | E4407B | MY46185649 | June 5, 2016 | June 4, 2017
Power Probe | R&S | NRP-Z23 | 100323 | July 24,2016 | July 23,2017
RF attenuator | N/A | RFA20db | 68 | N/A | N/A
EUT | PC

Page 8 of 26

FOR RADIATED EMISSION TEST (1GHZ ABOVE)
Radiated Emission Test Site
Name of Equipment | Manufacturer | Model Number | Serial
| | | Number | Last Calibration | Due Calibration
EMI Test Receiver | Rohde & Schwarz | ESCI | 101417 | July 3, 2016 | July 2, 2017
Horn Antenna (1G-18GHz) | SCHWARZBECK | BBHA9120D | 9120D-1246 | July 10, 2016 | July 9, 2017
Spectrum Analyzer | Agilent | E4411B | MY4511453 | July 3, 2016 | July 2, 2017
Signal Amplifier | SCHWARZBECK | BBV 9718 | 9718-269 | July 6, 2016 | July 5, 2017
RF Cable | SCHWARZBECK | AK9515H | 96220 | July 7, 2016 | July 6, 2017
3m Anechoic Chamber | CHENGYU | 966 | PTS-001 | June 5, 2016 | June 4, 2017
MULTI-DEVICE Positioning Controller | Max-Full | MF-7802 | MF780208339 | N/A | N/A
Horn Ant (18G-40GHz) | Schwarzbeck | BBHA 9170 | 9170-181 | June 5, 2016 | June 4, 2017
Power Probe | R&S | NRP-Z23 | 100323 | July 24,2016 | July 23,2017
RF attenuator | N/A | RFA20db | 68 | N/A | N/A
Conducted Emission Test Site Name of
EMI Test Receiver | Rohde & Schwarz | ESCI | 101417 | July 3, 2016 | July 2, 2017
Artificial Mains Network | Narda | L2-16B | 000WX31025 | July 7, 2016 | July 6, 2017
Artificial Mains Network (AUX) | Narda | L2-16B | 000WX31026 | July 7, 2016 | July 6, 2017
RF Cable | SCHWARZBECK | AK9515E | 96222 | July 3, 2016 | July 2, 2017
Shielded Room | CHENGYU | 843 | PTS-002 | June 5,2016 | June 4,2017
Equipment | Manufacturer | Model Number | Serial Number | Last
Calibration | Due Calibration

Conducted Emission Test Site Name of

EMI Test Receiver | Rohde & Schwarz | ESCI | 101417 | July 3, 2016 | July 2, 2017
Artificial Mains Network | Narda | L2-16B | 000WX31025 | July 7, 2016 | July 6, 2017
Artificial Mains Network (AUX) | Narda | L2-16B | 000WX31026 | July 7, 2016 | July 6, 2017
RF Cable | SCHWARZBECK | AK9515E | 96222 | July 3, 2016 | July 2, 2017
Shielded Room | CHENGYU | 843 | PTS-002 | June 5,2016 | June 4,2017
Equipment | Manufacturer | Model Number | Serial Number | Last
Calibration | Due Calibration

Page 9 of 26

### 4. SUMMARY OF TEST RESULTS

### 5. DESCRIPTION OF TEST MODES

The EUT has been operated in three modulations: GFSK independently.
NO. | TEST MODE DESCRIPTION
1 | Low channel TX
2 | Middle channel TX
3 | High channel TX
4 | Normal Operating (BT)
Note:
1. All the test modes can be supply by PC, only the result of the worst case was recorded in the report if no any records.
2. For Radiated Emission, 3axis were chosen for testing for each applicable mode.
3. Eut is operating at its maximum duty cycle>or equal 98%
IC RULES | DESCRIPTION OF TEST | RESULT
RSS-247, ISSUE 1 RSS-Gen, ISSUE 4 ANSI C63.10 | Antenna Requirement | Compliant
RSS-247, ISSUE 1 RSS-Gen, ISSUE 4 ANSI C63.10 | Radiated Emission | Compliant
RSS-247, ISSUE 1 RSS-Gen, ISSUE 4 ANSI C63.10 | Band Edges | Compliant
RSS-247, ISSUE 1 RSS-Gen, ISSUE 4 ANSI C63.10 | 6 dB&99% Bandwidth | Compliant
RSS-247, ISSUE 1 RSS-Gen, ISSUE 4 ANSI C63.10 | Conducted Power | Compliant
RSS-247, ISSUE 1 RSS-Gen, ISSUE 4 ANSI C63.10 | Maximum Conducted Output Power SPECTRAL Density | Compliant
RSS-247, ISSUE 1 RSS-Gen, ISSUE 4 ANSI C63.10 | Conduction Emission | Compliant

Page 10 of 26

### 6. ANTENNA REQUIREMENT

### 6.1. STANDARD APPLICABLE

According to RSS-247, An intentional radiator shall be designed to ensure that no antenna other than that furnished by the responsible party shall be used with the device. The use of a permanently attached antenna or of an antenna that uses a unique coupling to the intentional radiator shall be considered sufficient to comply with the provisions of this Section. The manufacturer may design the unit so that a broken antenna can be replaced by the user, but the use of a standard antenna jack or electrical connector is prohibited. Further, this requirement does not apply to intentional radiators that must be professionally installed, such as perimeter protection systems and some field disturbance sensors, or to other intentional radiators which, in accordance with Section RSS-247, must be measured at the installation site. However, the installer shall be responsible for ensuring that the proper antenna is employed so that the limits in this Part are not exceeded.

### 6.2. TEST RESULT

In addition to permanent antenna, the product could be connected with some detachable antennas. Please include them into this section.
Also, please note that U.FL / IPEX antenna connector is not considered as a type of unique antenna coupling. However, as the installation of this module would be done by OEM integrator, it could be considered as a professional installation.

Page 11 of 26

### 7. RADIATED EMISSION

### 7.1 MEASUREMENT PROCEDURE

1. Configure the EUT according to ANSI C63.10. The EUT was placed on the top of the turntable 0.8 meter above ground. The phase center of the receiving antenna mounted on the top of a height-variable antenna tower was placed 3 meters far away from the turntable.
2. Power on the EUT and all the supporting units. The turntable was rotated by 360 degrees to determine the position of the highest radiation.
3. The height of the broadband receiving antenna was varied between one meter and four meters above ground to find the maximum emissions field strength of both horizontal and vertical polarization.
4. For each suspected emissions, the antenna tower was scan (from 1 M to 4 M) and then the turntable was rotated (from 0 degree to 360 degrees) to find the maximum reading.
5. Set the test-receiver system to Peak or CISPR quasi-peak Detect Function with specified bandwidth under Maximum Hold Mode.
6. For emissions above 1GHz, use 1MHz VBW and RBW for peak reading. Then 1MHz RBW and 10Hz VBW for average reading in spectrum analyzer. The EUT was placed on the top of the turntable 1.5 meter above ground. The phase center of the receiving antenna mounted on the top of a height-variable antenna tower was placed 3 meters far away from the turntable.
7. When the radiated emissions limits are expressed in terms of the average value of the emissions, and pulsed operation is employed, the measurement field strength shall be determined by averaging over one complete pulse train, including blanking intervals, as long as the pulse train does not exceed 0.1 seconds. As an alternative (provided the transmitter operates for longer than 0.1 seconds) or in cases where the pulse train exceeds 0.1 seconds, the measured field strength shall be determined from the average absolute voltage during a 0.1 second interval during which the field strength is at its maximum values. 8.If the emissions level of the EUT in peak mode was 3 dB lower than the average limit specified, then testing will be stopped and peak values of EUT will be reported, otherwise, the emissions which do not have 3 dB margin will be repeated one by one using the quasi-peak method for below 1GHz.
9. For testing above 1GHz, the emissions level of the EUT in peak mode was lower than average limit (that means the emissions level in peak mode also complies with the limit in average mode), then testing will be stopped and peak values of EUT will be reported, otherwise, the emissions will be measured in average mode again and reported.
10. In case the emission is lower than 30MHz, loop antenna has to be used for measurement and the recorded data should be QP measured by receiver. High - Low scan is not required in this case.


Page 12 of 26

### 7.2 TEST SETUP

RADIATED EMISSION TEST SETUP 30MHz-1000MHz

RADIATED EMISSION TEST SETUP ABOVE 1000MHz

Page 13 of 26

### 7.3 LIMITS AND MEASUREMENT RESULT

RSS-247 Limit in the below table has to be followed
Frequencies (MHz) | Field Strength (micorvolts/meter) | Measurement Distance (meters)
0.009~0.490 | 2400/F(KHz) | 300
0.490~1.705 | 24000/F(KHz) | 30
1.705~30.0 | 30 | 30
30~88 | 100 | 3
88~216 | 150 | 3
216~960 | 200 | 3
Above 960 | 500 | 3

Note: All modes were tested For restricted band radiated emission,
the test records reported below are the worst result compared to other modes.

### 7.4 TEST RESULT

RADIATED EMISSION BELOW 30MHZ No emission found between lowest internal used/generated frequencies to 30MHz.

Page 14 of 26

RADIATED EMISSION BELOW 1GHZ RADIATED EMISSION TEST- (30MHZ-1GHZ) -HORIZONTAL


RESULT: PASS

Page 15 of 26

RADIATED EMISSION TEST- (30MHZ-1GHZ) -VERTICAL


RESULT: PASS

Note: 1. Factor=Antenna Factor + Cable loss, Margin=Measurement-Limit.
2. The “Factor” value can be calculated automatically by software of measurement system.
3. All modes were tested (matched worst case antenna), only the worst case record in the report

Page 16 of 26

RADIATED EMISSION ABOVE 1GHZ

Frequency | Meter Reading | Factor | Emission Level | Limits | Margin | Detector | Comment
(MHz) | (dBμV) | (dB) | (dBμV/m) | (dBμV/m) | (dB) | Type
Low Channel (2402 MHz)
4804 | 40.22 | 10.44 | 50.66 | 74 | -23.34 | Pk | Horizontal
4804 | 29.17 | 10.44 | 39.61 | 54 | -14.39 | AV | Horizontal
7206 | 42.06 | 12.39 | 54.45 | 74 | -19.55 | pk | Horizontal
7206 | 29.08 | 12.39 | 41.47 | 54 | -12.53 | AV | Horizontal
4804 | 43.10 | 10.4 | 53.50 | 74 | -20.50 | Pk | Vertical
4804 | 28.54 | 10.4 | 38.94 | 54 | -15.06 | AV | Vertical
7206 | 32.70 | 12.75 | 45.45 | 74 | -28.55 | Pk | Vertical
7206 | 27.95 | 12.75 | 40.70 | 54 | -13.30 | AV | Vertical
Mid Channel (2440 MHz)
4880 | 38.59 | 10.4 | 48.99 | 74 | -25.01 | Pk | Horizontal
4880 | 29.75 | 10.4 | 40.15 | 54 | -13.85 | AV | Horizontal
7320 | 40.26 | 12.75 | 53.01 | 74 | -20.99 | Pk | Horizontal
7320 | 30.80 | 12.75 | 43.55 | 54 | -10.45 | AV | Horizontal
4880 | 43.31 | 10.39 | 53.70 | 74 | -20.30 | Pk | Vertical
4880 | 27.98 | 10.44 | 38.42 | 54 | -15.58 | AV | Vertical
7320 | 39.87 | 12.68 | 52.55 | 74 | -21.45 | Pk | Vertical
7320 | 30.90 | 12.68 | 43.58 | 54 | -10.42 | AV | Vertical
High Channel (2480 MHz)
4960 | 43.23 | 10.39 | 53.62 | 74 | -20.38 | pk | Horizontal
4960 | 26.04 | 10.39 | 36.43 | 54 | -17.57 | AV | Horizontal
7440 | 39.36 | 12.68 | 52.04 | 74 | -21.96 | pk | Horizontal
7440 | 30.71 | 12.68 | 43.39 | 54 | -10.61 | AV | Horizontal
4960 | 37.05 | 10.39 | 47.44 | 74 | -26.56 | pk | Vertical
4960 | 27.13 | 10.39 | 37.52 | 54 | -16.48 | AV | Vertical
7440 | 39.85 | 12.68 | 52.53 | 74 | -21.47 | pk | Vertical
7440 | 30.97 | 12.68 | 43.65 | 54 | -10.35 | AV | Vertical

RESULT: PASS

Note: 1~25GHz scan with GFSK. No recording in the test report at least have 20dB margin. Factor = Antenna Factor + Cable Loss – Pre-amplifier.
Emission Level = Meter Reading + Factor
Margin = Emission - Leve Limit
All modes were tested(matched worst case antenna), only the worst case record in the report

Page 17 of 26

### 8. BAND EDGE EMISSION

### 8.1. MEASUREMENT PROCEDURE

1)Radiated restricted band edge measurements
The radiated restricted band edge measurements are measured with an EMI test receiver connected to the receive antenna while the EUT is transmitting
2)Conducted Emissions at the bang edge
a)The transmitter output was connected to the spectrum analyzer
b)Set RBW=100kHz,VBW=300kHz
c)Suitable frequency span including 100kHz bandwidth from band edge

### 8.2. TEST SET-UP

Radiated same as 6.2

Conducted set up

cable

EUT | Spectrum analyzer

Page 18 of 26

### 8.3. Radiated Test Result

Frequency | Reading Meter | Factor | Emission Level | Limits | Margin | Detector | Comment
(MHz) | (dBμV) | (dB) | (dBμV/m) | (dBμV/m) | (dB) | Type
Low Channel (2402 MHz)
2399.9 | 69.44 | -13 | 56.44 | 74 | -17.56 | peak | Horizontal
2399.9 | 55.13 | -13 | 42.13 | 54 | -11.87 | AVG | Horizontal
2400 | 65.17 | -12.99 | 52.18 | 74 | -21.82 | peak | Horizontal
2400 | 51.62 | -12.99 | 38.63 | 54 | -15.37 | AVG | Horizontal
2399.9 | 64.24 | -12.97 | 51.27 | 74 | -22.73 | peak | Vertical
2399.9 | 52.13 | -12.97 | 39.16 | 54 | -14.84 | AVG | Vertical
2400 | 66.18 | -12.94 | 53.24 | 74 | -20.76 | peak | Vertical
2400 | 54.18 | -12.94 | 41.24 | 54 | -12.76 | AVG | Vertical
High Channel (2480 MHz)
2483.5 | 68.40 | -12.78 | 55.62 | 74 | -18.38 | peak | Horizontal
2483.5 | 56.92 | -12.78 | 44.14 | 54 | -9.86 | AVG | Horizontal
2483.6 | 67.31 | -12.77 | 54.54 | 74 | -19.46 | peak | Horizontal
2483.6 | 54.25 | -12.77 | 41.48 | 54 | -12.52 | AVG | Horizontal
2483.5 | 70.36 | -12.76 | 57.60 | 74 | -16.40 | peak | Vertical
2483.5 | 53.45 | -12.76 | 40.69 | 54 | -13.31 | AVG | Vertical
2483.6 | 65.98 | -12.72 | 53.26 | 74 | -20.74 | peak | Vertical
2483.6 | 53.43 | -12.72 | 40.71 | 54 | -13.29 | AVG | Vertical

RESULT: PASS
Note: Factor=Antenna Factor + Cable loss - Amplifier gain,
Emission Level = Meter Reading + Factor
Margin= Emission Level -Limit.
The “Factor” value can be calculated automatically by software of measurement system.
All modes were tested (matched worst case antenna), only the worst case record in the report

Page 19 of 26
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

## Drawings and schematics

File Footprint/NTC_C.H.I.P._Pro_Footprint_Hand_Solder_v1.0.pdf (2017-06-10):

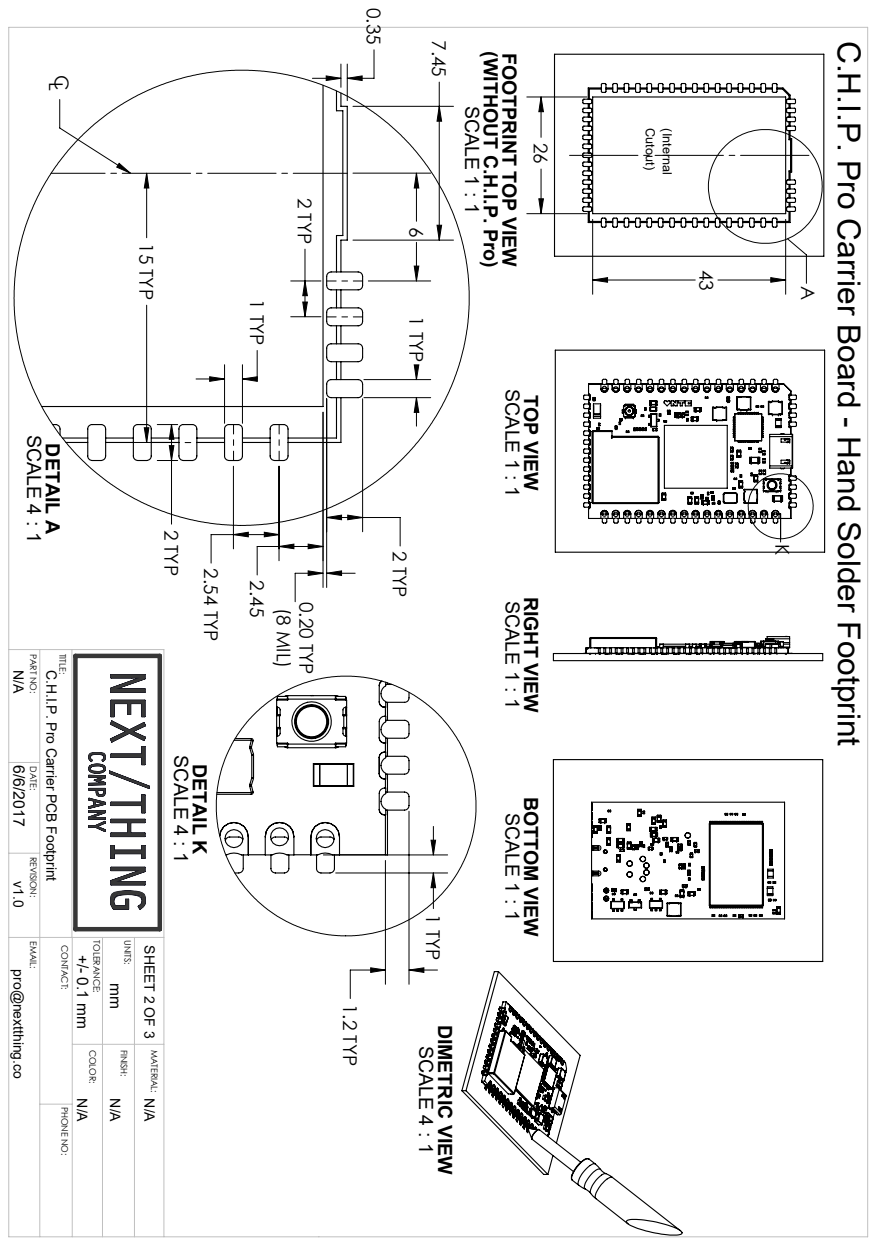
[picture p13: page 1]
Cutout); (Internal; 1 TYP; 2 TYP; 0.20 TYP (8 MIL); 2.54 TYP; 15 TYP; DETAIL A; SCALE 4 : 1; 1.2 TYP; DETAIL K; BOTTOM VIEW SCALE 1 : 1; DIMETRIC VIEW SCALE 4 : 1; (WITHOUT C.H.I.P. Pro); SCALE 1 : 1; SCALE 1 : 1 TOP VIEW; RIGHT VIEW; COLOR:; FINISH:; REVISION:; UNITS:; TITLE:; EMAIL:; CONTACT:; SHEET 2 OF 3; DATE:; PHONE NO:; MATERIAL:; PART NO:; TOLERANCE:

C.H.I.P. Pro Carrier Board - Hand Solder Footprint

FOOTPRINT TOP VIEW

pro@nextthing.co v1.0 N/A

C.H.I.P. Pro Carrier PCB Footprint

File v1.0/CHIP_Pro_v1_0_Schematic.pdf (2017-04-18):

# Schematics Index：

# P01: REVISION HISTORY

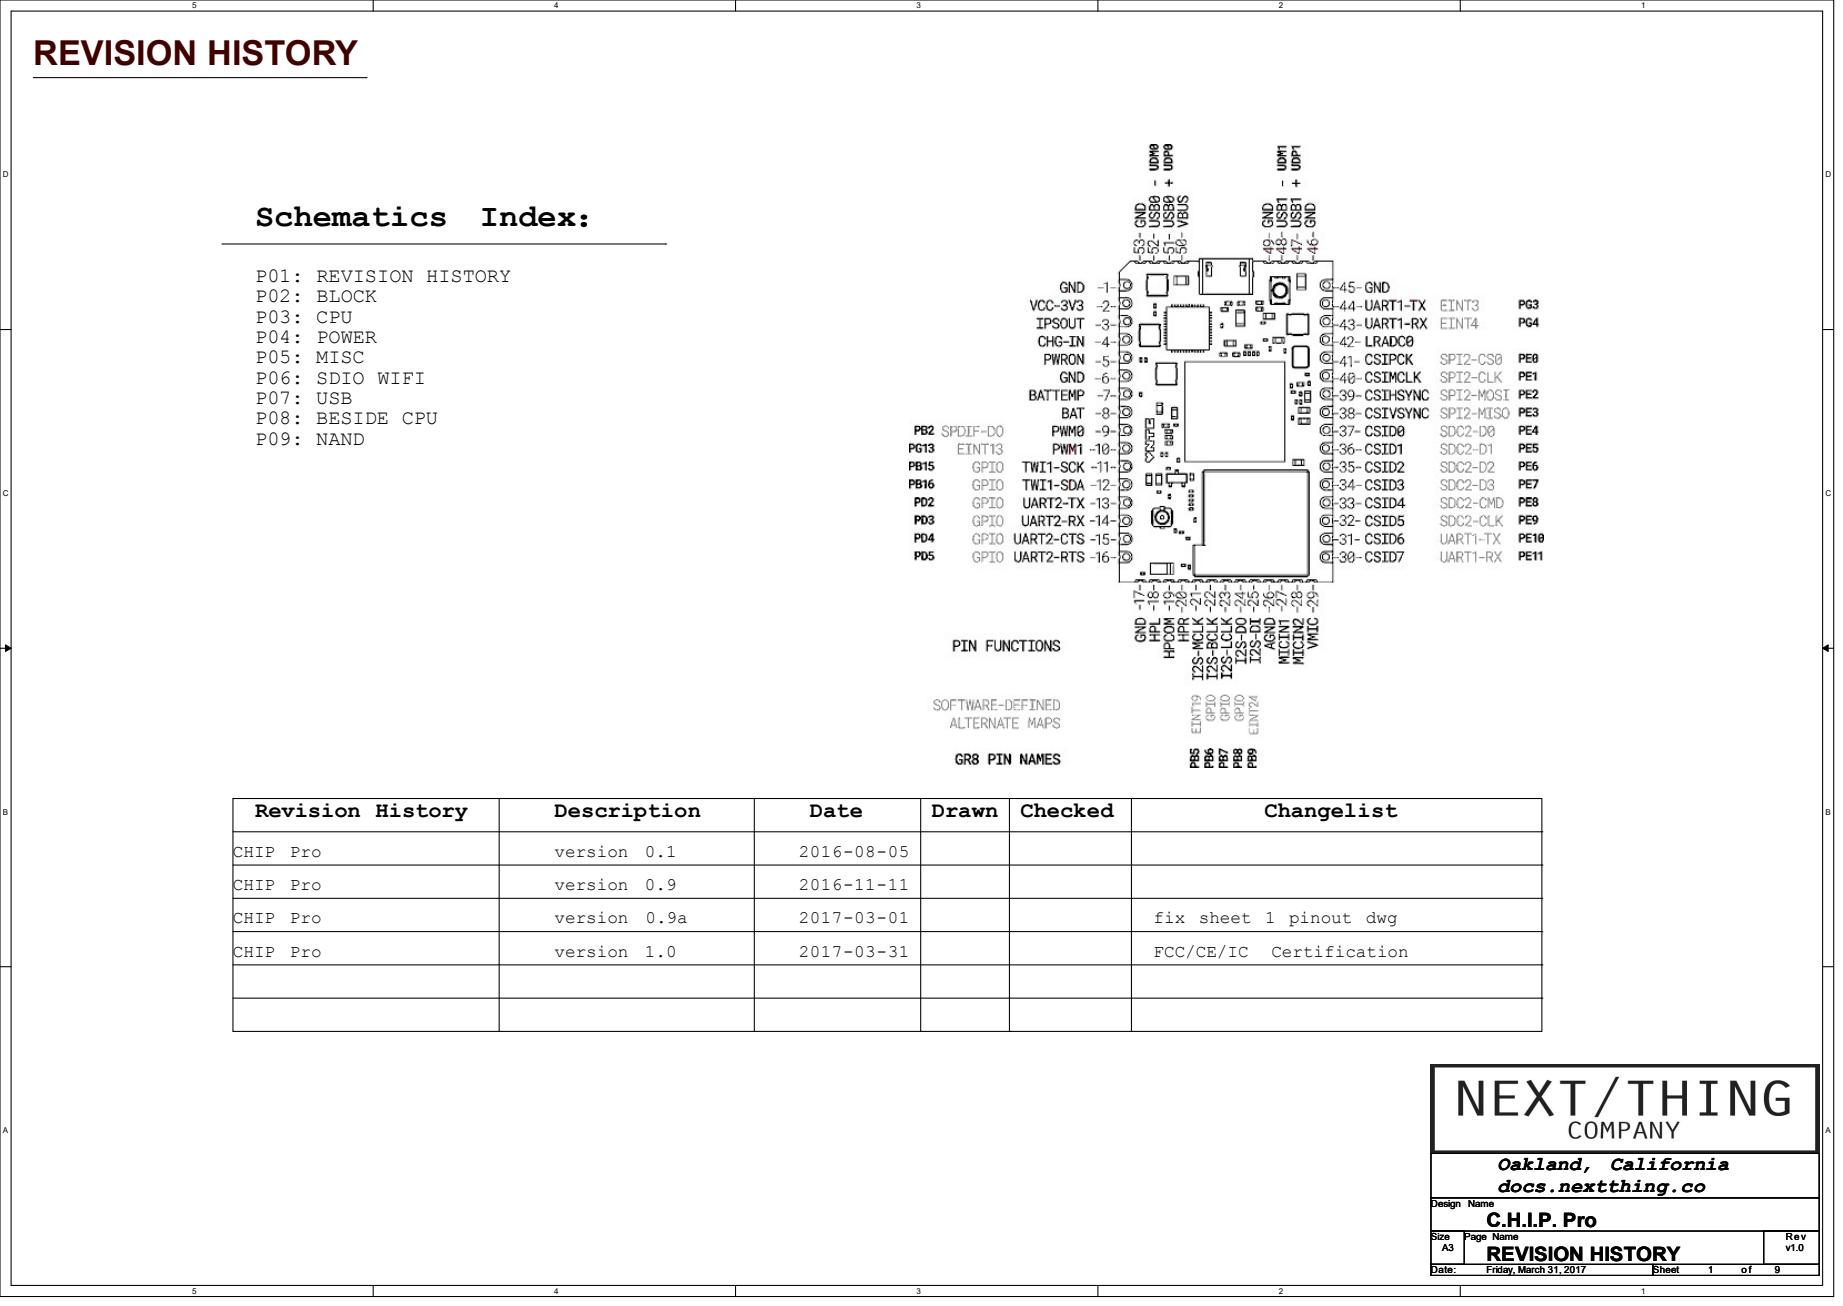
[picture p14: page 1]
P02: BLOCK P03: CPU P04: POWER P05: MISC P06: SDIO WIFI P07: USB P08: BESIDE CPU P09: NAND; REVISION HISTORY; Revision History; Description; Date; Drawn; Checked; Changelist; CHIP Pro; version 0.9; version 0.9a; version 0.1; version 1.0; Design Name; Size; Page Name; Date:; Sheet; v1.0 C.H.I.P. Pro A3; Friday, March 31, 2017

fix sheet 1 pinout dwg
FCC/CE/IC Certification

Oakland, California
docs.nextthing.co

# BLOCK

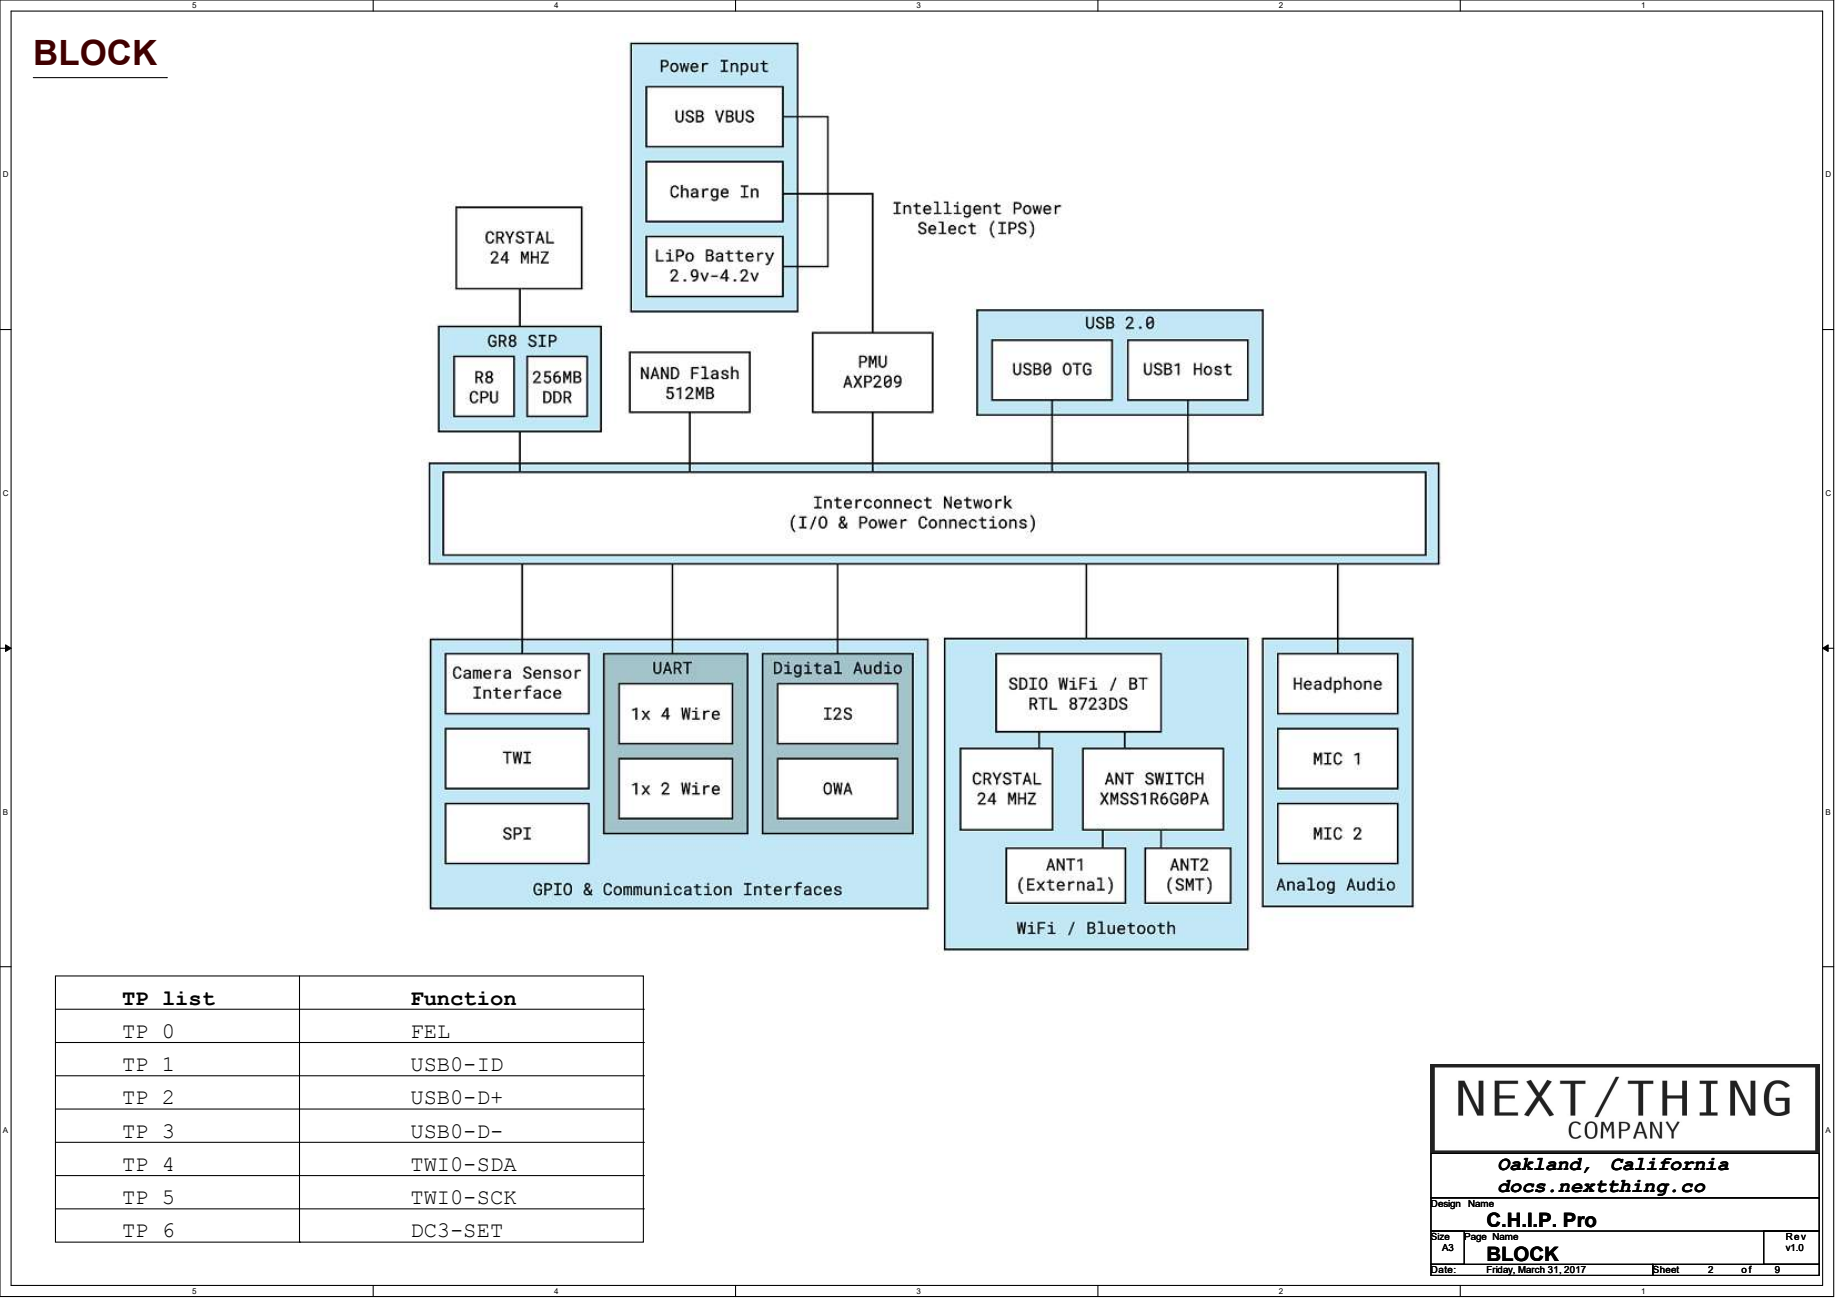
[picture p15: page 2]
TP list; Function; FEL USB0-ID USB0-D+ USB0-D- TWI0-SDA TWI0-SCK DC3-SET; BLOCK; v1.0 C.H.I.P. Pro A3; Friday, March 31, 2017

Oakland, California
docs.nextthing.co

CPU | NAND

# SYS

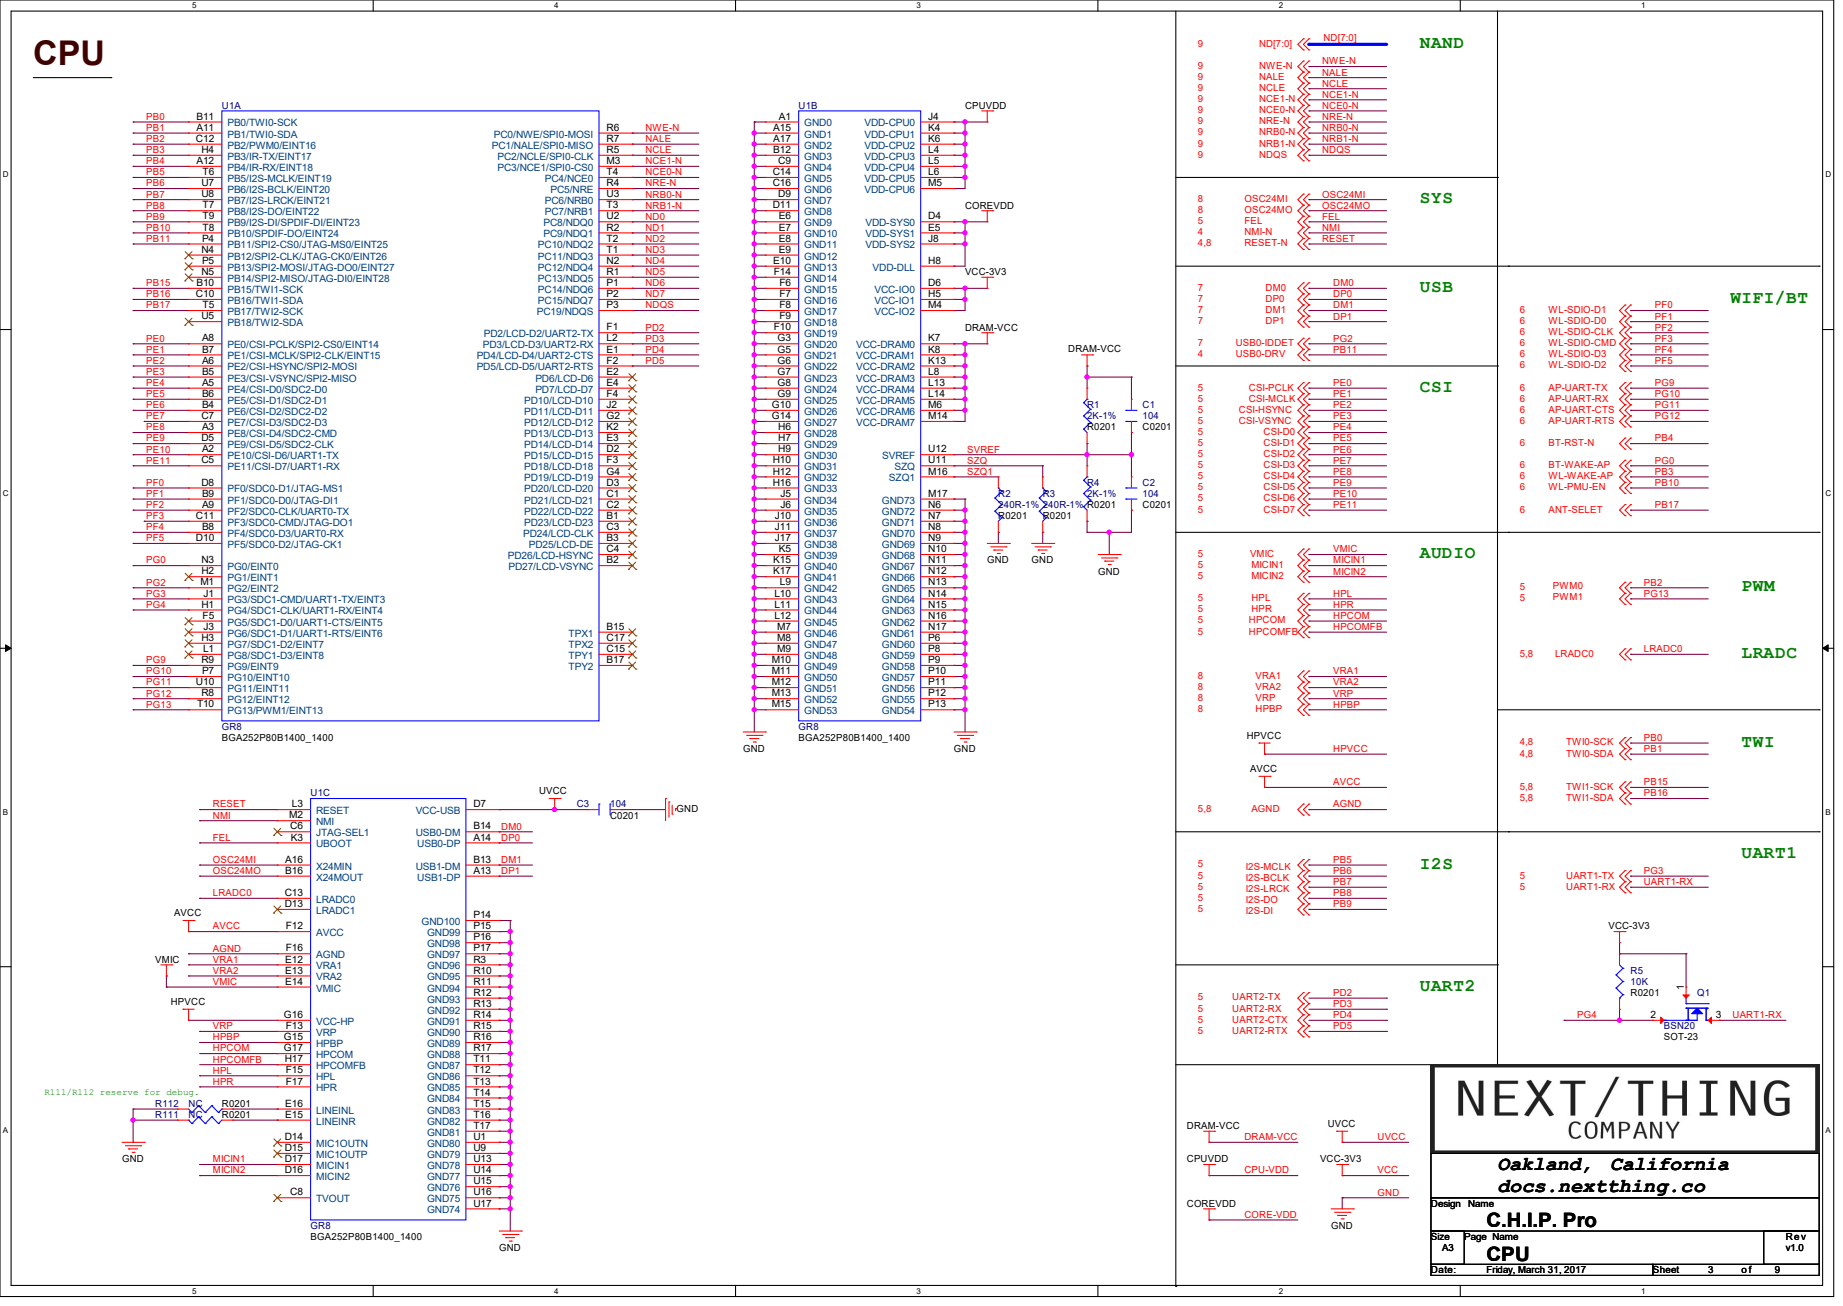
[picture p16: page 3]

VDD-CPU0 J4 VDD-CPU1 K4 VDD-CPU2 K6 VDD-CPU3 L4 VDD-CPU4 L5 VDD-CPU5 L6 VDD-CPU6 M5 VDD-DLL H8 VDD-SYS0 D4 VDD-SYS1 E5 VDD-SYS2 J8 VCC-DRAM0 K7 VCC-DRAM1 K8 VCC-DRAM2 K13 VCC-DRAM3 L8 VCC-DRAM4 L13 VCC-DRAM5 L14 VCC-DRAM6 M6 VCC-IO0 D6 VCC-IO1 H5 VCC-IO2 M4 GND25 G9 GND26 G10 GND27 G14 GND28 H6 GND29 H7 GND30 H9 GND31 H10 GND32 H12 GND33 H16
GND4 C9 GND5 C14 GND6 C16 GND7 D9 GND8 D11 GND9 E6 GND10 E7 GND11 E8 GND12 E9 GND13 E10 GND14 F14 GND15 F6 GND16 F7 GND17 F8 GND18 F9 GND44 L11 GND45 L12 GND43 L10 GND42 L9

PB0/TWI0-SCK B11 PB1/TWI0-SDA A11 PB2/PWM0/EINT16 C12 PB3/IR-TX/EINT17 H4 PB4/IR-RX/EINT18 A12 PB5/I2S-MCLK/EINT19 T6 PB6/I2S-BCLK/EINT20 U7 PB7/I2S-LRCK/EINT21 U8 PB8/I2S-DO/EINT22 T7 PB9/I2S-DI/SPDIF-DI/EINT23 T9 PB10/SPDIF-DO/EINT24 T8 PB11/SPI2-CS0/JTAG-MS0/EINT25 P4 PB12/SPI2-CLK/JTAG-CK0/EINT26 N4 PB13/SPI2-MOSI/JTAG-DO0/EINT27 P5 PB14/SPI2-MISO/JTAG-DI0/EINT28 N5 PB15/TWI1-SCK B10 PB16/TWI1-SDA C10 PB17/TWI2-SCK T5 PB18/TWI2-SDA U5 PE0/CSI-PCLK/SPI2-CS0/EINT14 A8 PE1/CSI-MCLK/SPI2-CLK/EINT15 B7 PE2/CSI-HSYNC/SPI2-MOSI A6 PE3/CSI-VSYNC/SPI2-MISO B5 PE4/CSI-D0/SDC2-D0 A5 PE5/CSI-D1/SDC2-D1 B6 PE6/CSI-D2/SDC2-D2 B4 PE7/CSI-D3/SDC2-D3 C7 PE8/CSI-D4/SDC2-CMD A3 PE9/CSI-D5/SDC2-CLK D5 PE10/CSI-D6/UART1-TX A2 PE11/CSI-D7/UART1-RX C5 PF0/SDC0-D1/JTAG-MS1 D8 PF1/SDC0-D0/JTAG-DI1 B9 PF2/SDC0-CLK/UART0-TX A9 PF3/SDC0-CMD/JTAG-DO1 C11 PF4/SDC0-D3/UART0-RX B8 PF5/SDC0-D2/JTAG-CK1 D10 PG0/EINT0 N3 PG1/EINT1 H2 PG2/EINT2 M1 PG3/SDC1-CMD/UART1-TX/EINT3 J1 PG4/SDC1-CLK/UART1-RX/EINT4 H1 PG5/SDC1-D0/UART1-CTS/EINT5 F5 PG6/SDC1-D1/UART1-RTS/EINT6 J3 PG7/SDC1-D2/EINT7 H3 PG8/SDC1-D3/EINT8 L1 PG9/EINT9 R9 PG10/EINT10 P7 PG11/EINT11 U10 PG12/EINT12 R8 PG13/PWM1/EINT13 T10

PC1/NALE/SPI0-MISO R7 PC0/NWE/SPI0-MOSI R6 PC3/NCE1/SPI0-CS0 M3 PC2/NCLE/SPI0-CLK R5 PC5/NRE R4 PC6/NRB0 U3 PC8/NDQ0 U2 PC10/NDQ2 T2 PC11/NDQ3 T1 PC13/NDQ5 R1 PC12/NDQ4 N2 PC19/NDQS P3 PC14/NDQ6 P1 PC9/NDQ1 R2 PC7/NRB1 T3 PC4/NCE0 T4 PC15/NDQ7 P2

PD2/LCD-D2/UART2-TX F1 PD3/LCD-D3/UART2-RX L2 PD4/LCD-D4/UART2-CTS E1 PD5/LCD-D5/UART2-RTS F2 PD6/LCD-D6 E2 PD7/LCD-D7 E4 PD10/LCD-D10 F4 PD11/LCD-D11 J2 PD12/LCD-D12 G2 PD13/LCD-D13 K2 PD14/LCD-D14 E3 PD15/LCD-D15 D2 PD18/LCD-D18 F3 PD19/LCD-D19 G4 PD20/LCD-D20 D3 PD21/LCD-D21 C1 PD22/LCD-D22 C2 PD23/LCD-D23 B1 PD24/LCD-CLK C3 PD25/LCD-DE B3 PD26/LCD-HSYNC C4 PD27/LCD-VSYNC B2

HPBP HPL NMI RESET OSC24MI OSC24MO

VCC-USB D7 USB0-DM B14 USB0-DP A14 USB1-DM B13 USB1-DP A13 HPBP G15

# POWER/PMU

# VCC-1V8 AVCC

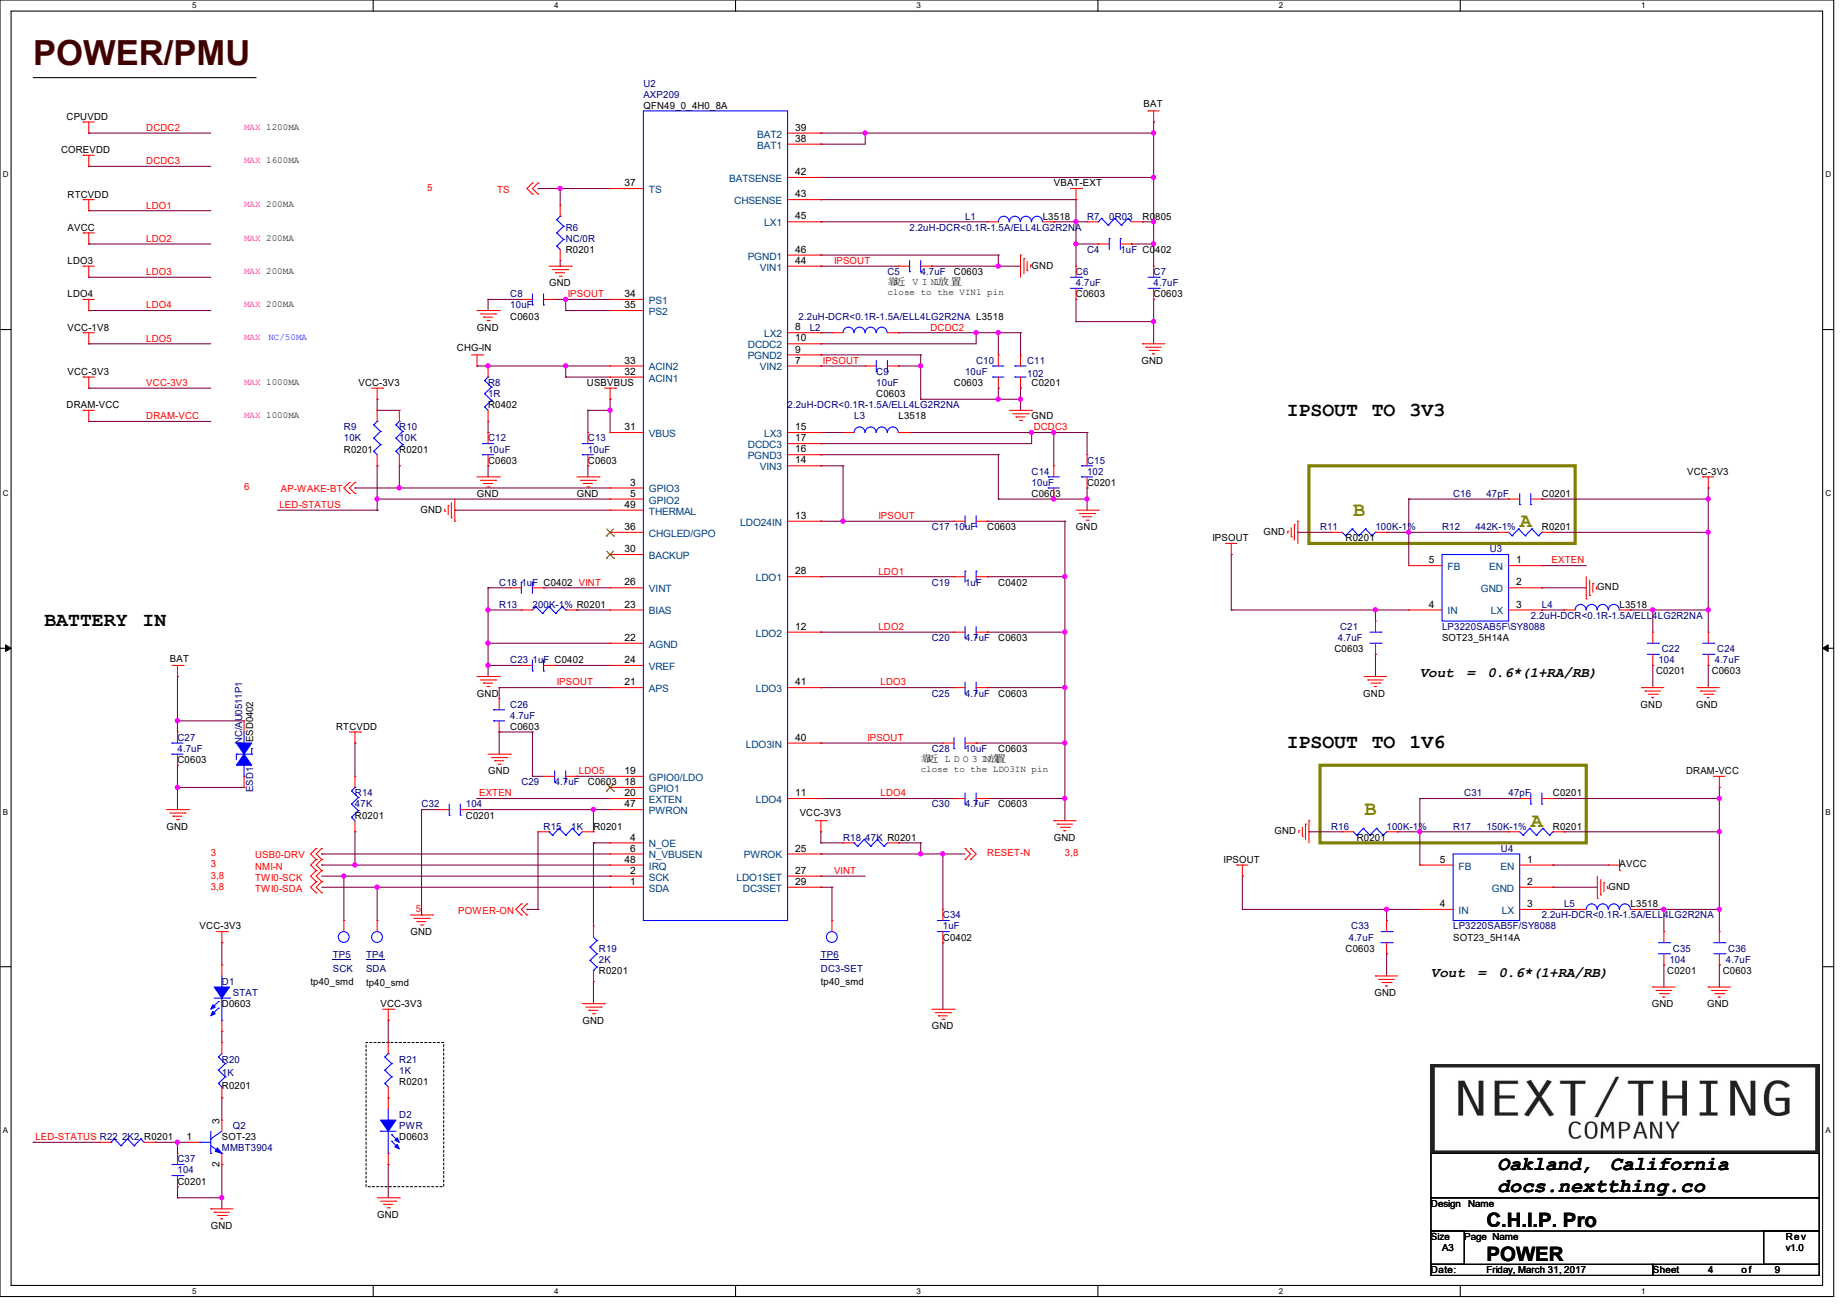
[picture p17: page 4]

BATSENSE 42 CHSENSE 43 VIN1 44
BACKUP 30 VBUS 31 ACIN1 32 ACIN2 33 PS1 34 PS2 35 CHGLED/GPO 36

close to the VIN1 pin

靠近 L D O 3 IN放置
close to the LDO3IN pin

# MISC

# PWM0 TSUART2-RTX UART2-TX

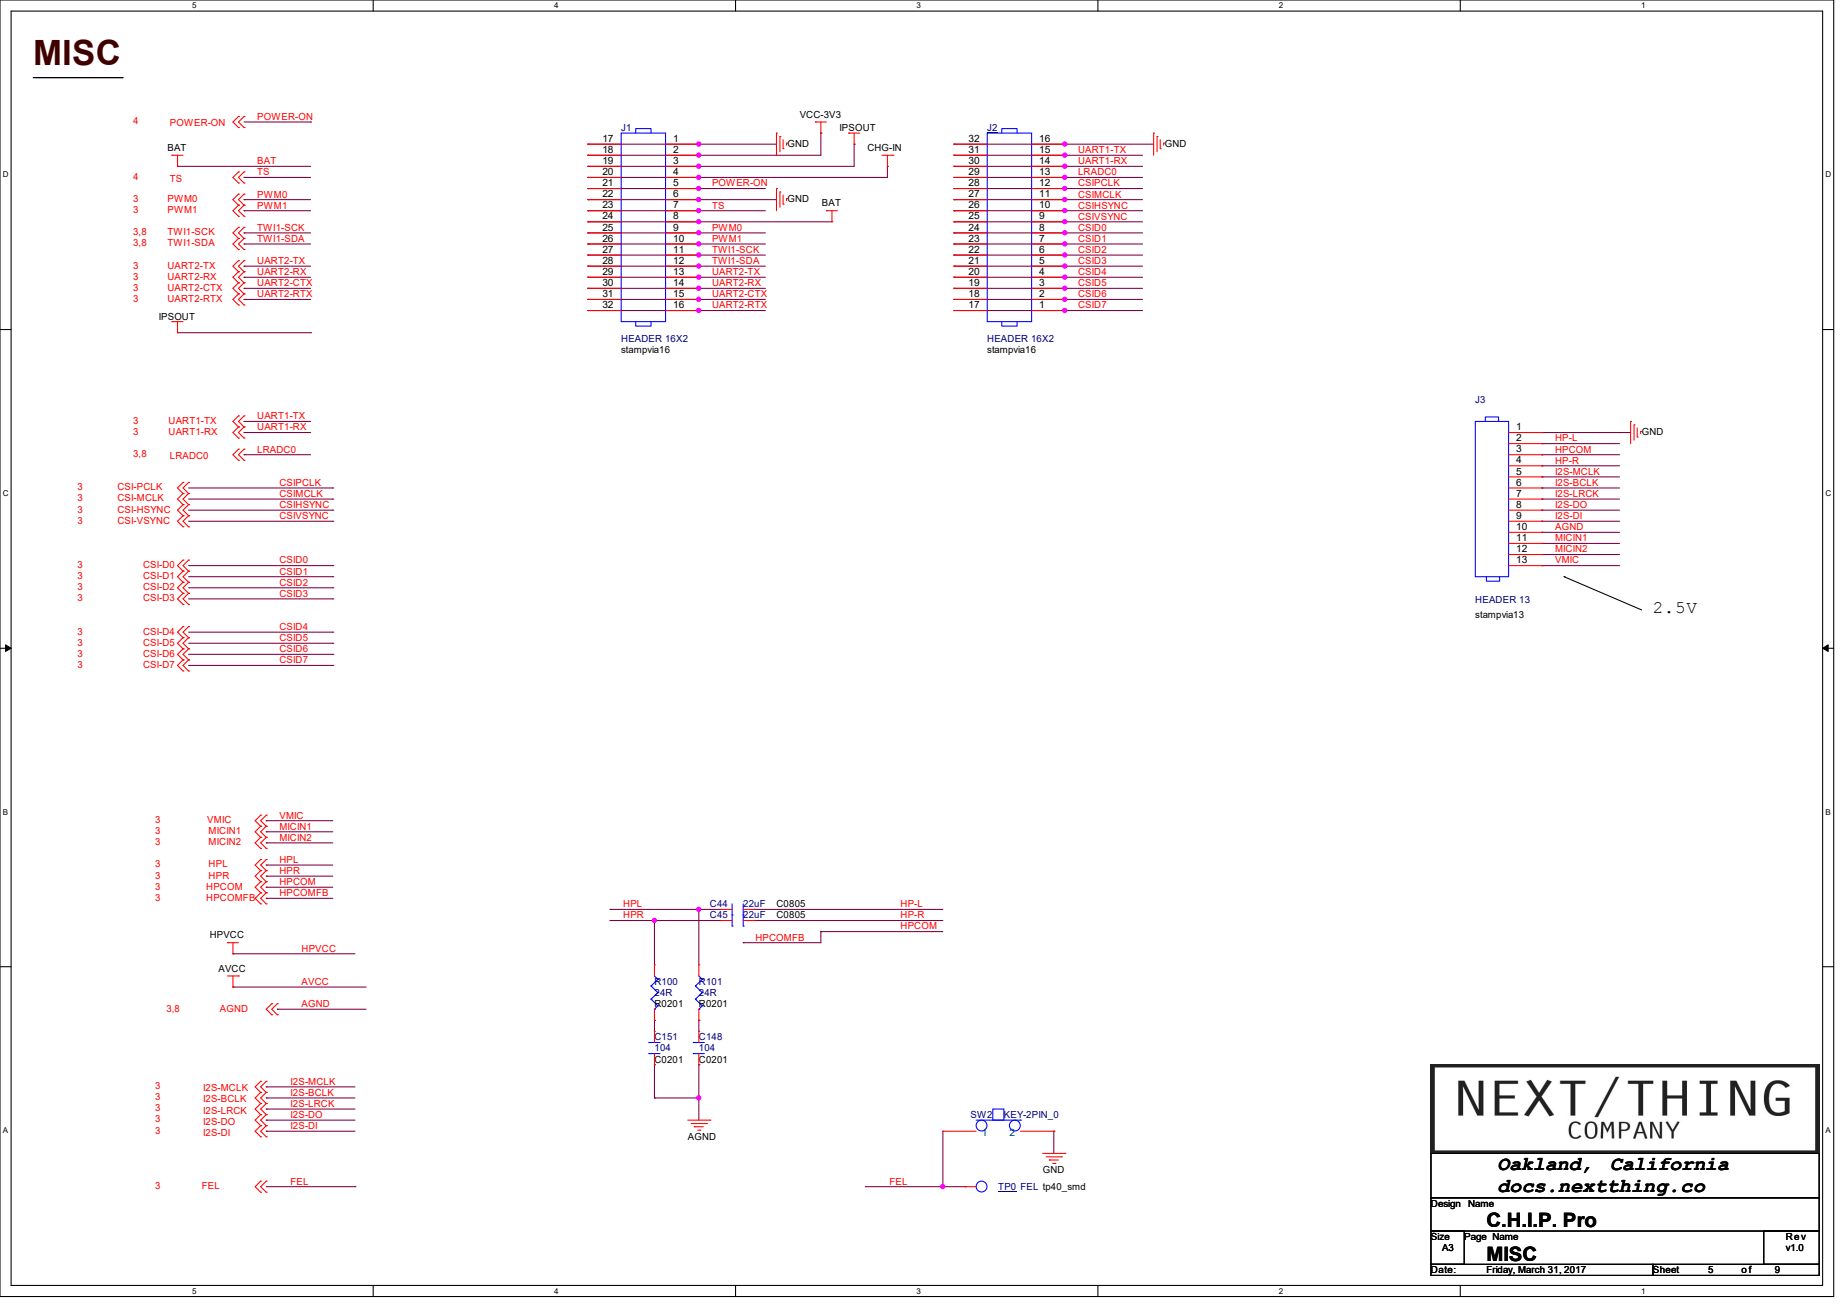
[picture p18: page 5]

IPSOUT GND BAT GND

TWI1-SCK
TWI1-SDA UART2-RTX UART2-CTX UART2-RX UART2-TX

A

B

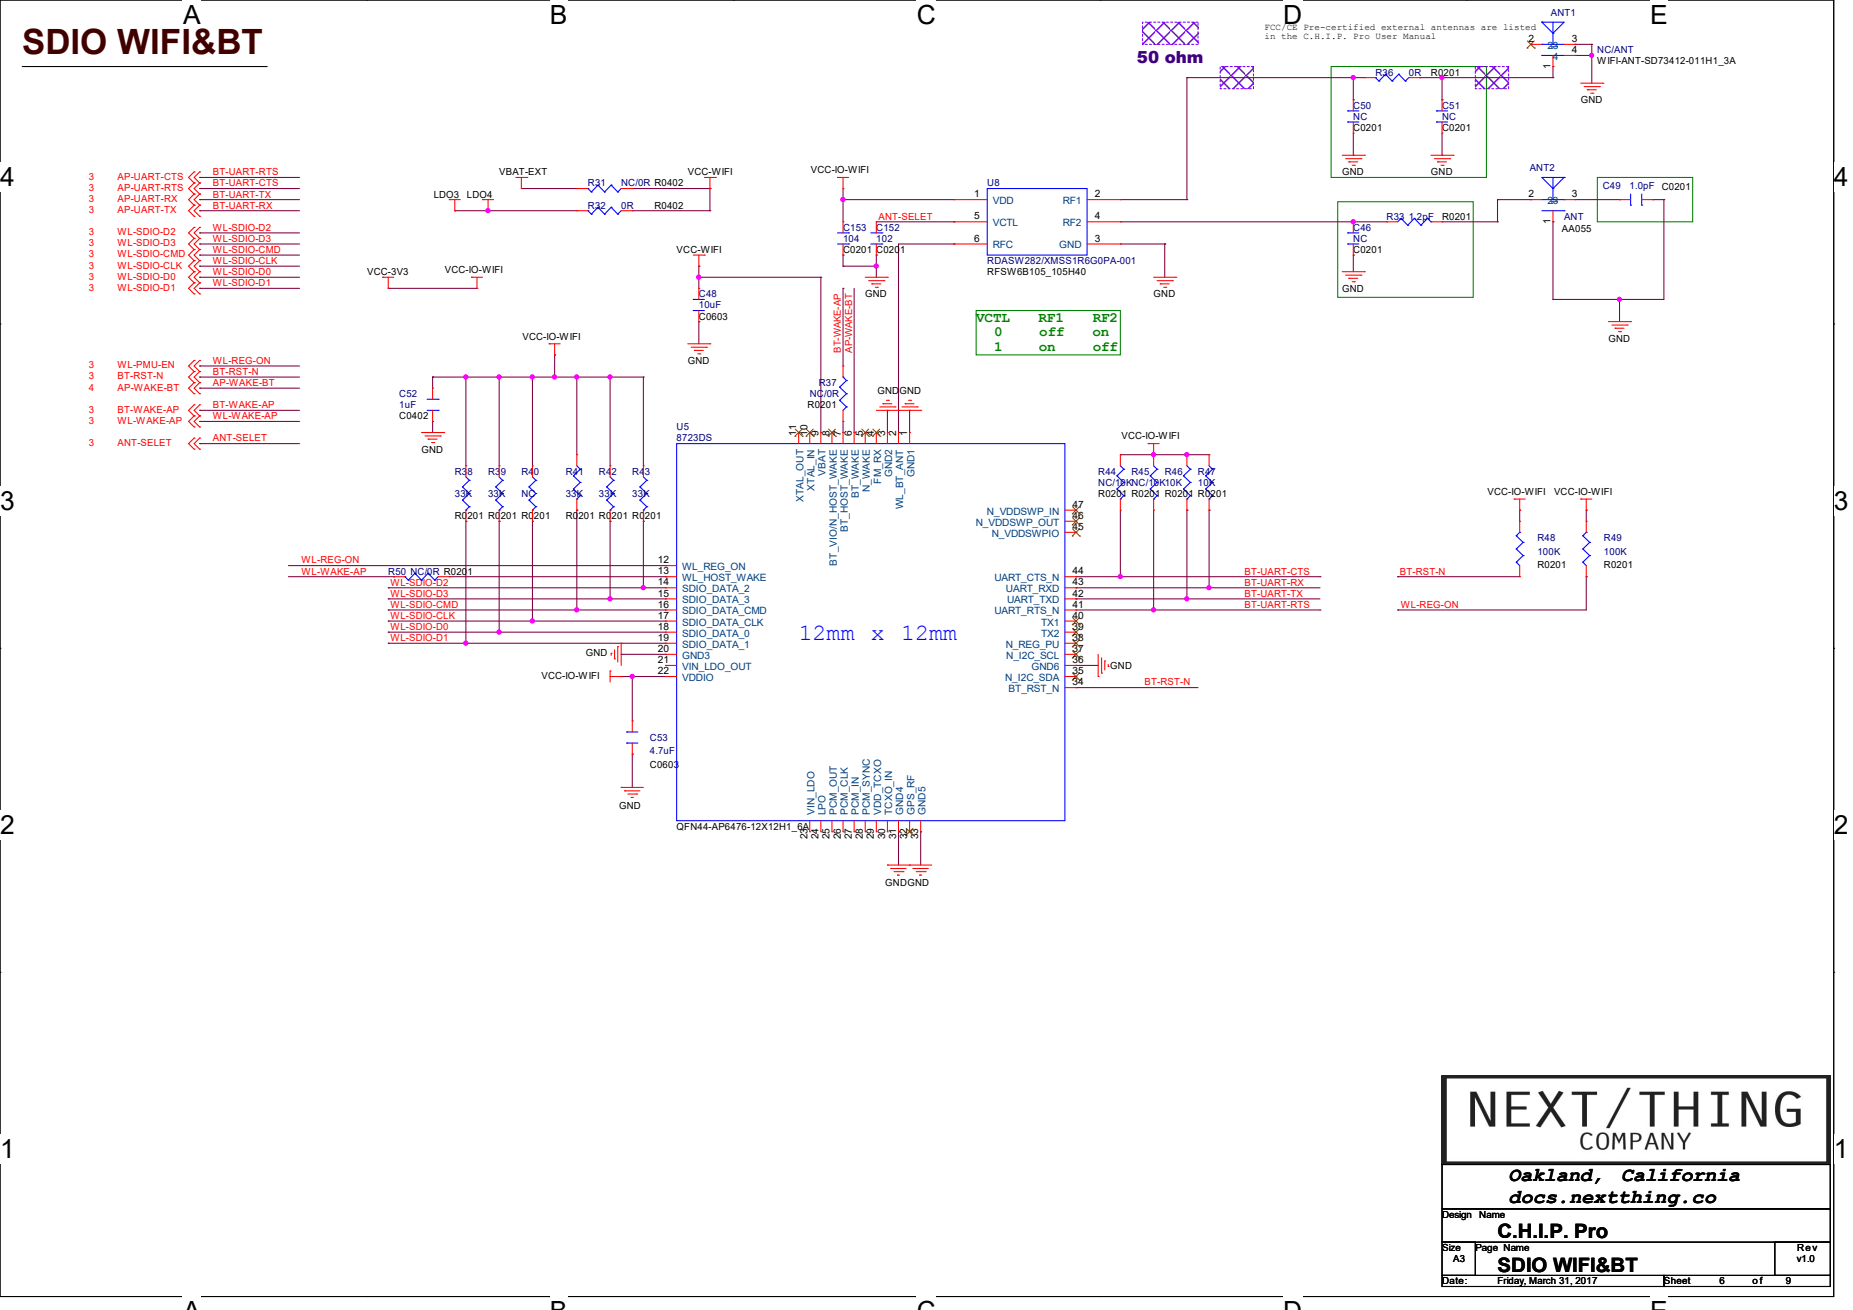
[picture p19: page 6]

FCC/CE Pre-certified external antennas are listed
in the C.H.I.P. Pro User Manual

BT-UART-RTS
BT-UART-CTS
BT-UART-TX
AP-WAKE-BT BT-RST-N WL-SDIO-D2 WL-SDIO-D3 WL-SDIO-CMD WL-SDIO-CLK WL-SDIO-D0 WL-SDIO-D1 BT-UART-RX

BT-RST-N WL-REG-ON WL-REG-ON

BT-RST-N WL-SDIO-CLK

# USB

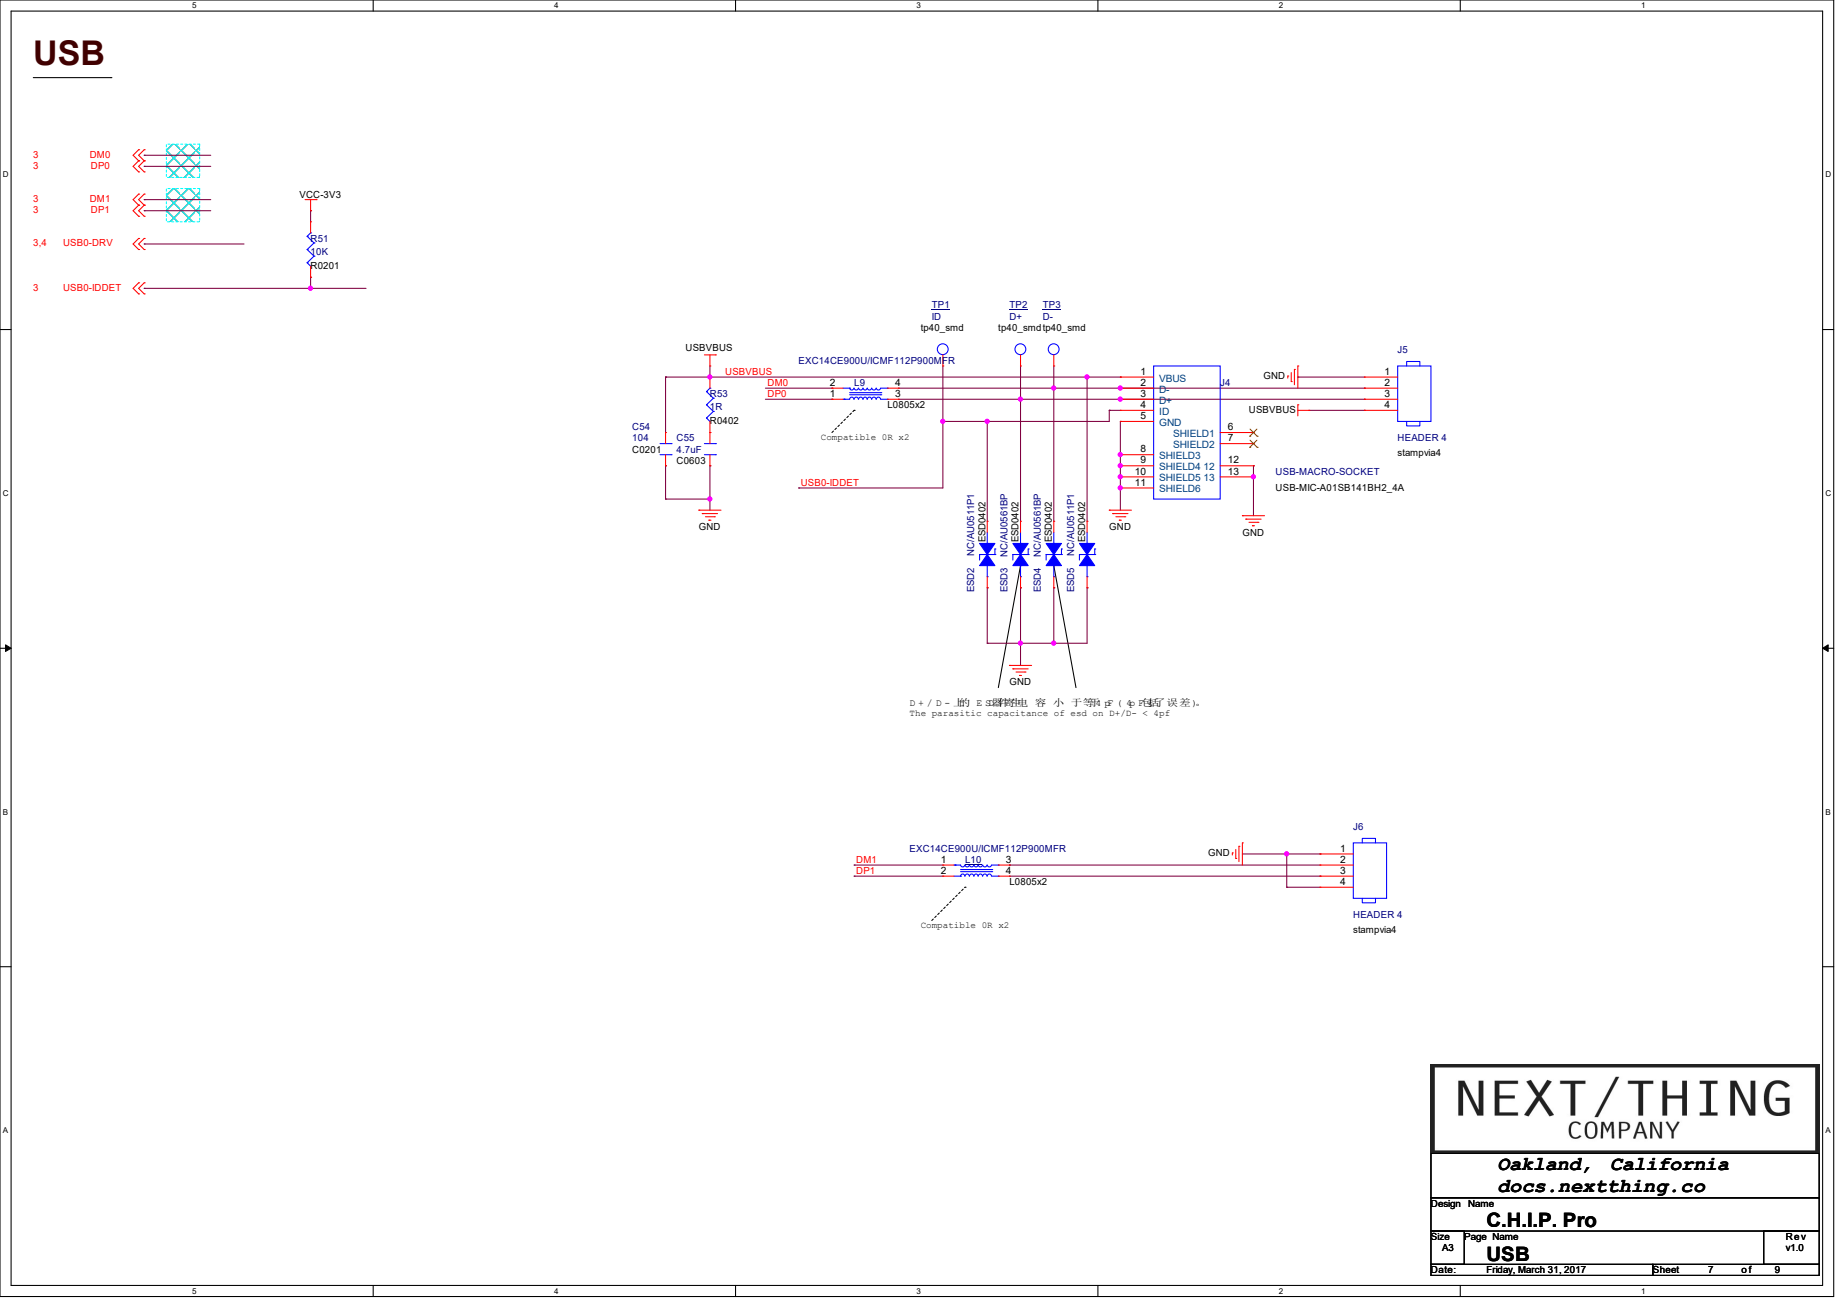
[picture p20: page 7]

4 ESD⁴ NC/AU⁰⁵⁶¹BP ESD⁰⁴⁰² TP2 D+

4 ESD³ NC/AU⁰⁵⁶¹BP ESD⁰⁴⁰²

D + / D - 上的 E SD器件寄生电 容 小 于等于4 pF ( 4p F包括了误差)。
The parasitic capacitance of esd on D+/D- < 4pf

# DRAM

# PIO-INTFACE

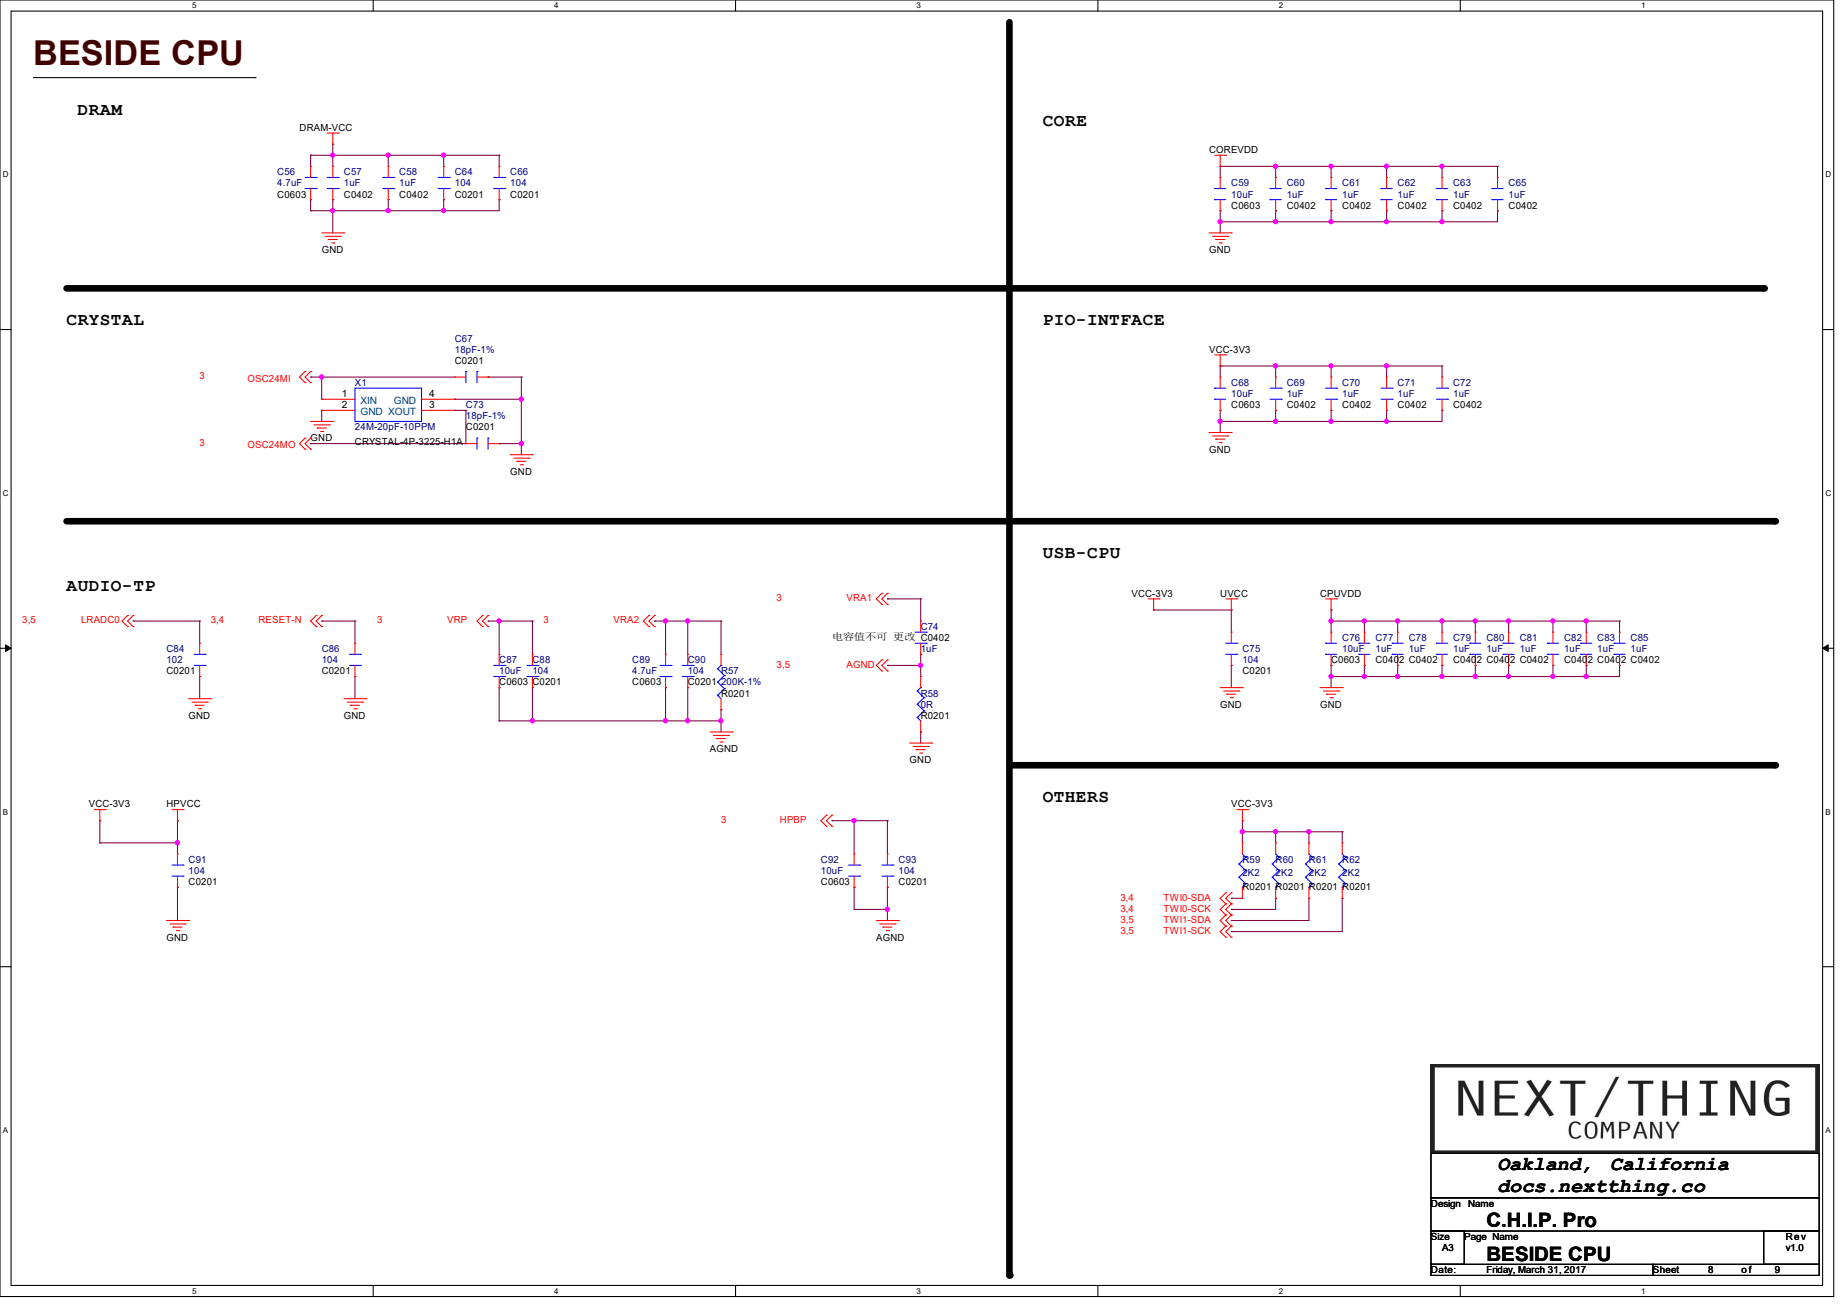
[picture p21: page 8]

# NAND

# NALE NRB1-N

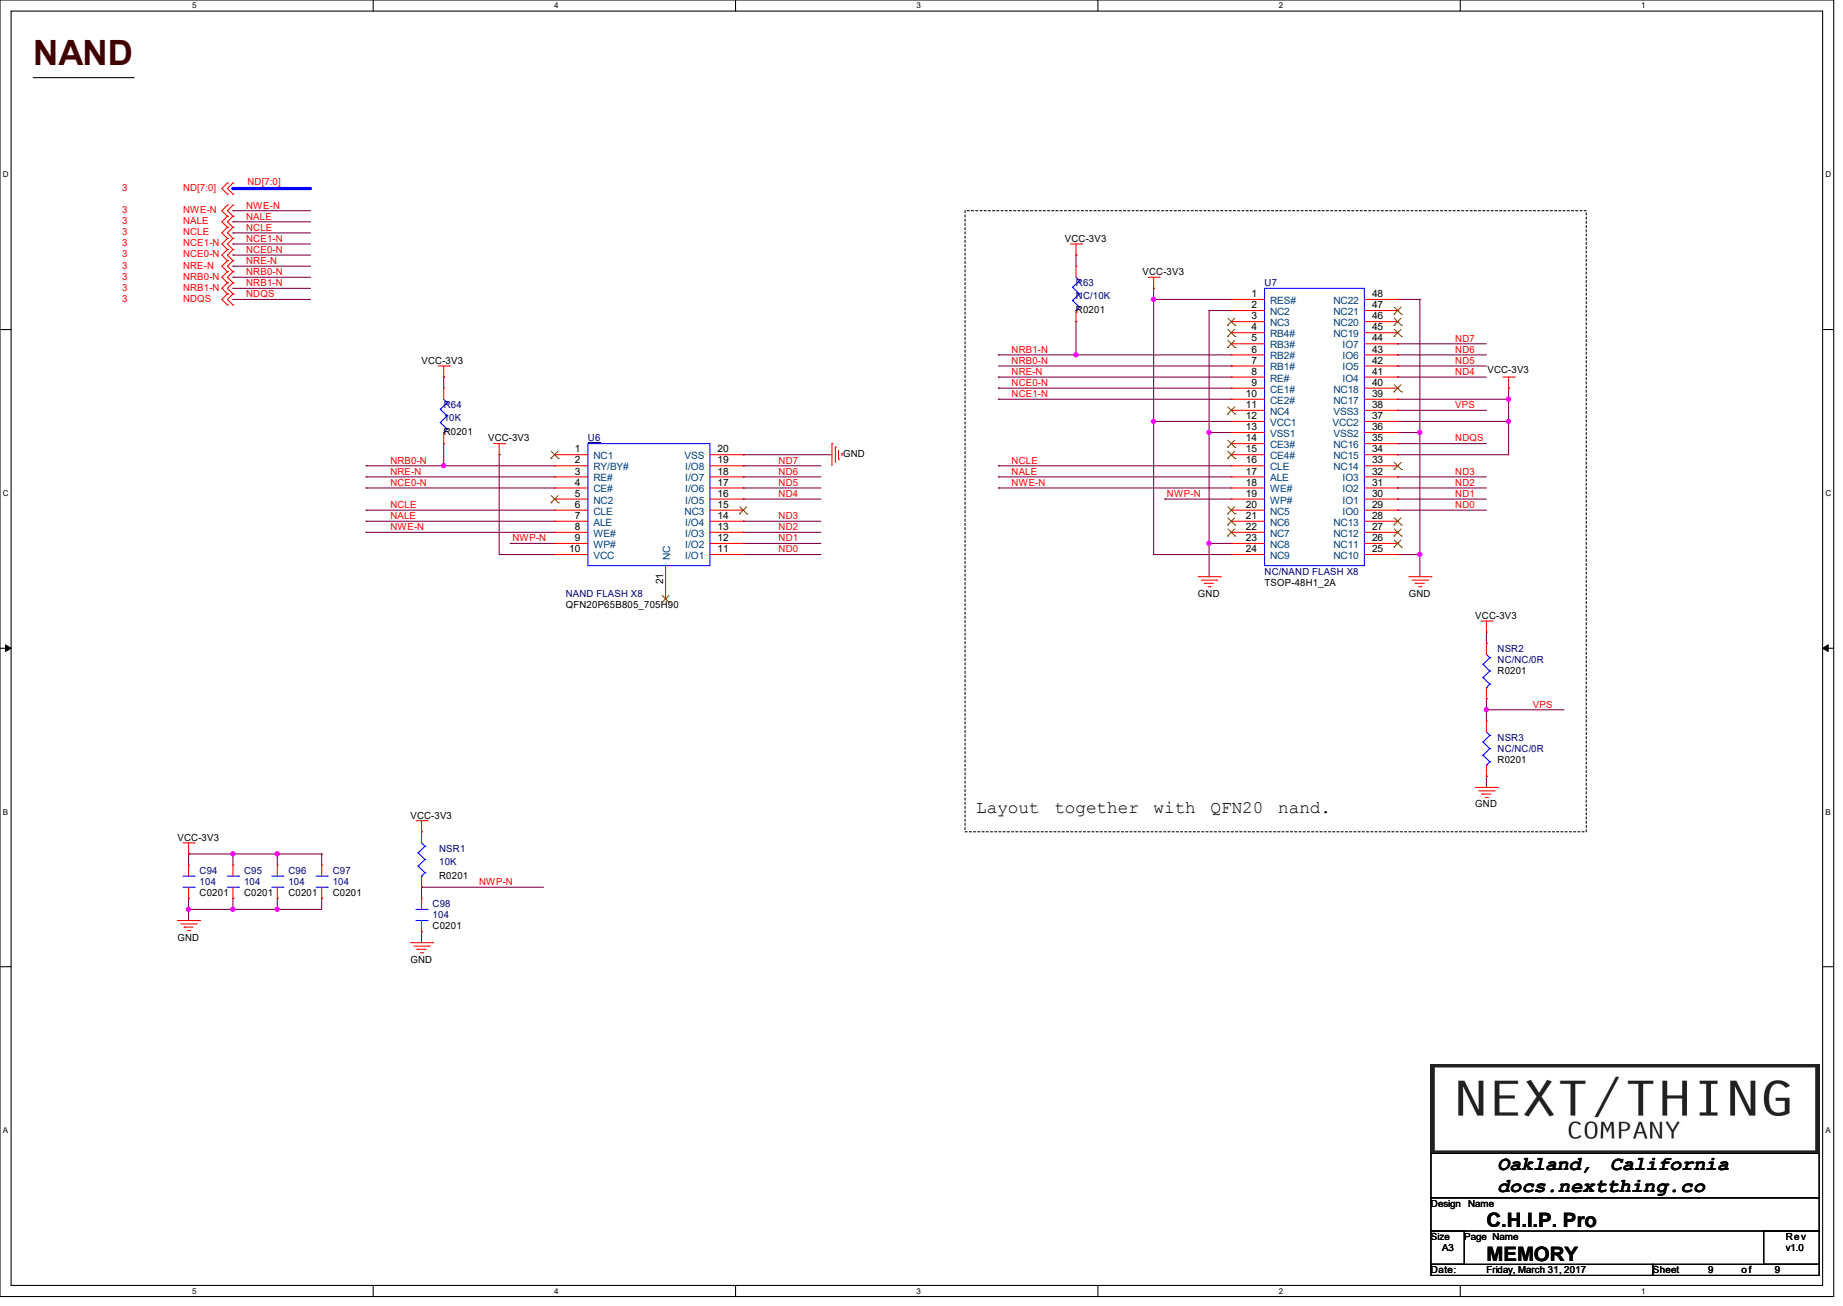
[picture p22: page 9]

R0201 NAND FLASH X8 U6 QFN20P65B805_705H90 CLE 6 ALE 7 RE# 3 VCC 10 CE# 4 NC2 5 WE# 8 WP# 9 NC1 1 RY/BY# 2

Layout together with QFN20 nand. NWP-N

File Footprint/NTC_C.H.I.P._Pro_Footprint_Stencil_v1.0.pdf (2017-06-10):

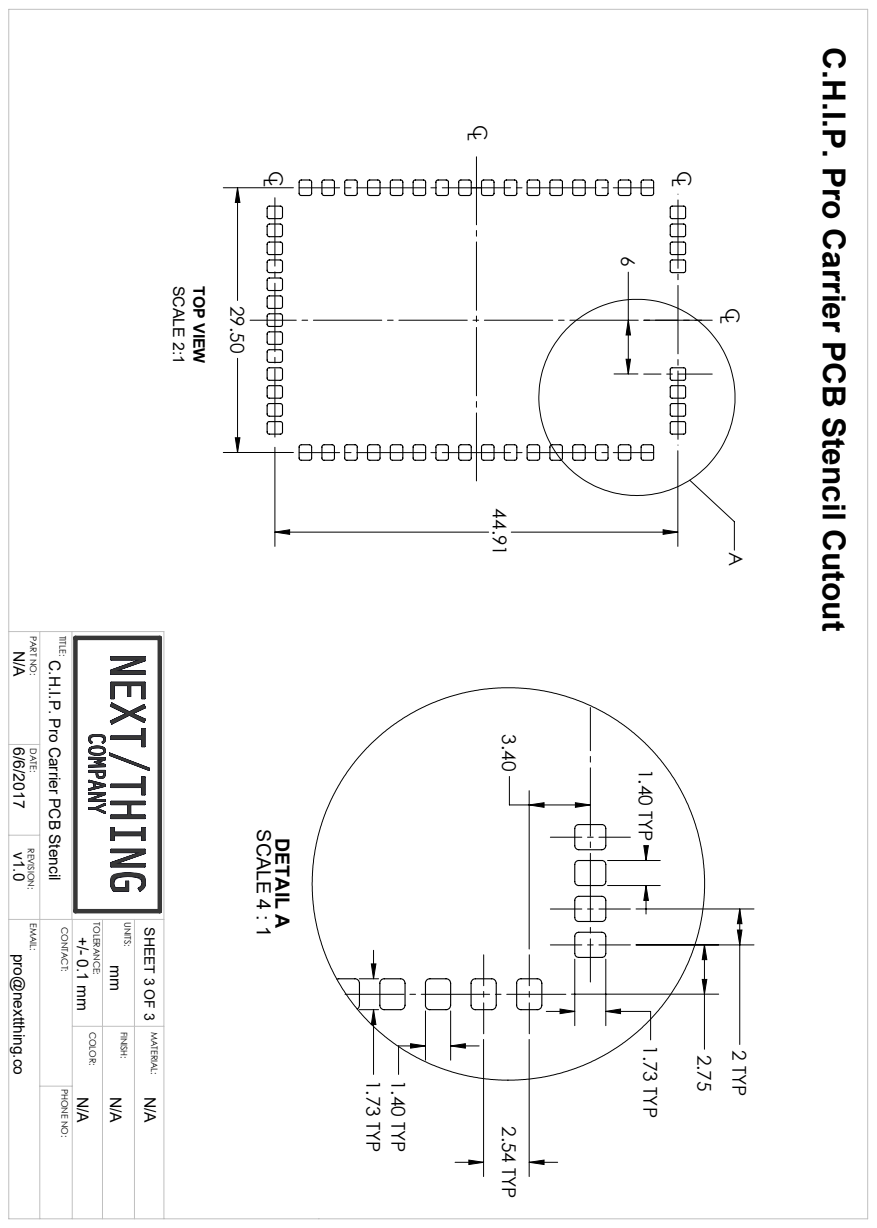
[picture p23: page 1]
LC 2 TYP; 2.54 TYP; 1.73 TYP 1.40 TYP; 1.73 TYP; 1.40 TYP; DETAIL A; SCALE 4 : 1; SCALE 2:1; TOP VIEW; COLOR:; FINISH:; REVISION:; UNITS:; TITLE:; EMAIL:; CONTACT:; SHEET 3 OF 3; DATE:; PHONE NO:; MATERIAL:; PART NO:; TOLERANCE:

C.H.I.P. Pro Carrier PCB Stencil Cutout

pro@nextthing.co v1.0 N/A

C.H.I.P. Pro Carrier PCB Stencil

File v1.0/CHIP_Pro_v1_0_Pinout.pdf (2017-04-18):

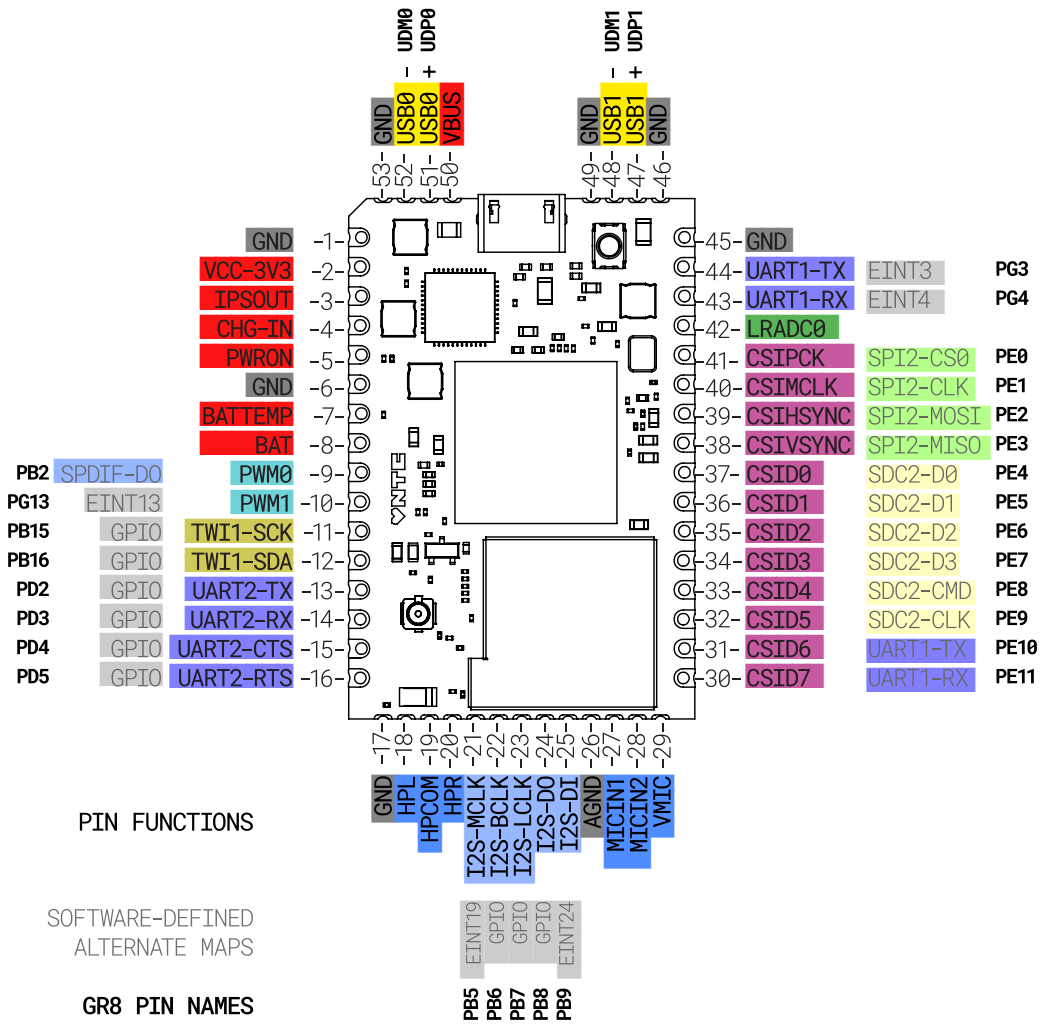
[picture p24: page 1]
DDD DDDDDD DDDDDD DDDDDD DDDDDD DDD DDDDDD DDDDDD DDDD DDDD DDDDDDD DDDDDDD DDDDDDD DDDDDDD DDDDDDDD DDDDDDDD; DDDDDDD DDDDD DDDD DDDD DDDD DDDD DDDD DDDD; DDD DDDDDDD DDDDDDD DDDDDD DDDDDDD DDDDDDD DDDDDDD DDDDDDD DDDDD DDDDD DDDDD DDDDD DDDDD DDDDD DDDDD DDDDD; DDDDD DDDDD; DDDDDDD DDDDDDD DDDDDDDD DDDDDDDD DDDDDD DDDDDD DDDDDD DDDDDD DDDDDDD DDDDDDD DDDDDDD DDDDDDD; DDDDD; DDDD

DDD DDDD DDDD DDDD

DDD DDDD DDDD DDD

DDD DDD DDDDD DDD DDDDDDD DDDDDDD DDDDDDD DDDDD DDDDD DDDD DDDDDD DDDDDD DDDD

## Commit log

2016-10-11 DATASHEETS!!!!!!!!!!!!!!!!!!!!
    \(• ◡•)/
2016-10-11 latest footprint
2017-01-09 Footprints for all the EDAs!
2017-03-02 Added latest 3D CAD (.STEP) file of CHIP Pro
    Complete CHIP Pro PCBA solid assembly, created in Solidworks 2015.
2017-03-02 Add BOM and component datasheets, replace pinout errata, temporarily remove footprint and app note errata
2017-03-07 Updated 3D Model and Mechanical Drawing Files
    Updates include:
    - test point locations
    - shape of landing pads
    - minor shift in component placement (antenna, resistors, caps)
    - minor reduction in USB height
    [NTC-100456_C.H.I.P._Pro_Mechanical_Drawing_v1.0_2017-03-06.DXF]
2017-04-18 Update Datasheet to 1.03 w/ FCC info, add v1.0 PCB Sources
    [CHIP_PRO_v1_0.DSN, CHIP_PRO_v1_0.brd]
2017-05-04 Updated CHIP Pro BOM (sourcing info only)
    Updated the "CHIP_Pro_v1_0_BOM.pdf" file with changes to sourcing information only. No parts changed.
2017-06-09 Delete CHIP_PRO-Footprint.png
    Replacing with updated footprint diagrams + solder paste stencil
    - SMT
    - hand solder
    - solder paste stencil
2017-06-09 updated footprints + stencil
    hand solder
    SMT
    solder paste stencil
2017-06-10 updated pdfs - footprints and stencil
    - stencil
    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
2017-07-10 external wifi antenna spec sheet
2017-11-17 update CHIP Pro footprint w hand and smt placement variants
